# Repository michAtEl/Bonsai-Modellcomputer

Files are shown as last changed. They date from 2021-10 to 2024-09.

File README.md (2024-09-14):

# Bonsai-Modellcomputer
Der Bonsai-Modellcomputer wurde von Klaus Merkert für den Einsatz im Informatikunterricht entwickelt. Auf folgender Seite findet man unter anderem Schaltpläne und Platinenlayouts von Klaus Merkert zum Bau eines Bonsai-Modellcomputers:
http://www.hsg-kl.de/faecher/inf/material/bonsai/

Es gibt auch eine Simulation des Lerncomputers (https://bonsai.pinyto.de/), die im digitalen Informatik-Schulbuch http://inf-schule.de verwendet wird.

Viele Bauteile, die in den Plänen von Klaus Merkert verwendet werden, wurden abgekündigt und sind heue (Stand 2021) nicht mehr verfügbar.
Ziel dieses Projektes ist es deshalb, eine Version des Bonsai-Modellcomputer zu entwickeln, die möglichst leicht nachgebaut werden kann.

# Projekstatus
Der Prototyp funktioniert und wurde im Unterricht eingesetzt. In den Github-Issues sind einige kleinere Probleme beschrieben, die vor einem weiteren Nachbau behoben werden könnten.

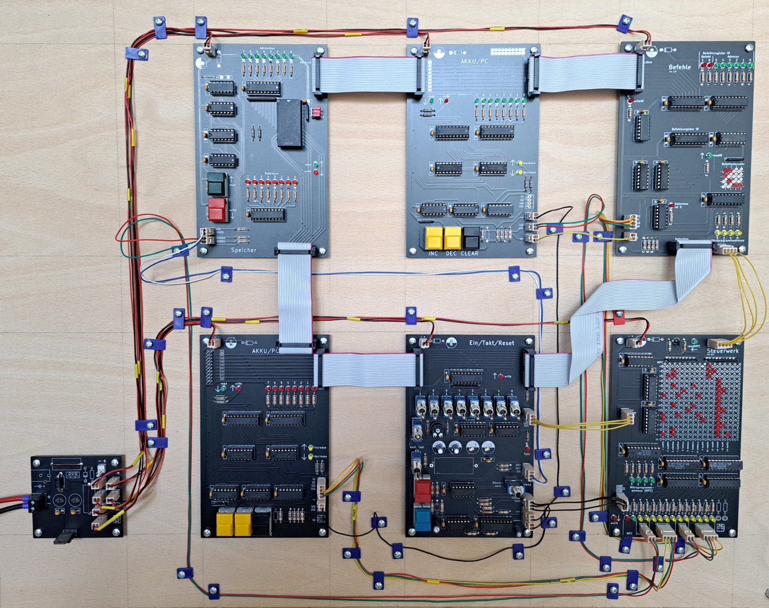
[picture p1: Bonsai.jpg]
Bonsai-Modellcomputer


# Änderungen gegenüber den Plänen von Klaus Merkert
- Die Namen und Reihenfolge der Steuersignale wurden an den Simulator angepasst (vgl. https://bonsai.pinyto.de/documentation/micro/)
- Alle Schaltpläne und Platinen wurden mit der Software KiCad gezeichnet (http://kicad.org).
- Für die Platinen wurden neue Layouts entwickelt, damit die Möglichkeiten eines doppelseitigen Layouts besser genutzt werden können.
- Die Steckverbinder zur Verbindung der Steuersignale sowie der Spannungsversorgung mit den Platinen wurden ersetzt durch Reichelt PSK (Alternativ kann man Molex KK verwenden. Diese Steckverbinder sind besser, aber auch deutlich teurer).
- Alle Bauteile der Familie 74LS wurden durch Bauteile der Familien 74HC oder 74HCT ersetzt.
- Zur Nullentdeckung auf der Platine Befehle wurde eine Wired-And-Verknüpfung mit Open-Collector-Ausgängen verwendet. Diese Wired-And-Verknüpfung wurde durch Gatter in einem 74HC08 ersetzt.
- Zur Erzeugung eines automatischen Taktsignals wird ein Mikrocontroller (Atmega 48-20P) verwendet. Der Quellcode liegt im Verzeichnis EinTaktReset-src. Der Quellcode kann mit dem Microchip Studio compiliert werden. Der Mikrocontroller kann anschließend über den ISP-Header auf der Platine EinTaktReset programmiert werden.

# Eine Bonsai nachbauen
## Beschaffung der Bauteile
- Flachbandkabel: Diese Flachbandkabel kann man aus IDE-Kabeln herstellen.
- Taster Digitast: Diese Schalter sind in den letzten Jahren sehr teuer geworden (ca. 5€ pro Taster). Kompatible Nachbauten findet man auf der Seite https://de.aliexpress.com/ unter der Bezeichnung PB86. Zur Sicherheit: Datenblatt (insbesondere Abmessungen und interne Schaltung) prüfen!
- Die Steckverbinder 

## Platinen fertigen lassen
Die Pläne wurden mit KiCad gezeichnet. In den *.kicad_sch-Dateien befinden sich die Schaltpläne, die Platinenlayouts sind in den *.kicad_pcb-Dateien. Um die Platinen fertigen zu lassen, muss man das Platinenlayout in ein Format exportieren, dass der Hersteller versteht. In der Regel ist das Gerber. Die Gerber-Exporte, die bei dem Prototypen verwendet wurden, liegen im Verzeichnis gerber. Diese Gerber-Dateien wurden von https://jlcpcb.com/ problemlos gefertigt.

## Platinen bestücken
Es werden nur bedrahtete Bauteile (keine SMD-Bauteile) verwendet, da bedrahtete Bauteile von Lötanfängern (z.B. Schülern) leichter bestückt werden können. Es ist sinnvoll, bei allen ICs je einen Sockel zu verwenden.

Der Bestückungsdruck der Platinen wird für Hinweise zur Bedienung des Rechners verwendet.
Die Bezeichnungen der Bauteile stehen nicht im Bestückungsdruck.
Man erfährt diese Bezeichnungen, indem man das KiCad-Projekt zu der Platinen, an der man gerade arbeitet, betrachtet. Dazu öffnet man zunächst die Projektdatei (.kicad_pro). Aus der Kicad-Projektansicht kann man dann den Schaltplan und das Board mit einem Doppelclick öffnen. Wenn man die Dateien so öffnet, sind Schaltplan und Board verknüpft. D.h.: Klickt man im Schaltplan / Board auf ein Bauteil, so wird dieses Bauteil automatisch auch im Bard / Schaltplan hervorgehoben. So versteht man leichter, welche Aufgabe ein bestimmtes Bauteil auf dem Board hat. 

Es empfiehlt sich, die Platinen in der folgenden Reihenfolge zu bestücken:
- Spanngsversorgung (KiCad-Projekt power-schmal). Diese Platine wird später benötigt, um andere Platinen zu testen.
- Akku und PC. Diese Platinen können einzeln getestet werden. Achtung: Die Platinen sind gleich, sie unterscheiden sich jedoch in der Farbe der LEDs und den Widerständen R2 und R2 (vgl. Schaltplan sowie [Bonsai.jpg](Bonsai.jpg))
- Speicher
- Ein/Takt/Reset. Nun können alle bisher gebauten Platinen gemeinsam getestet werden. Man verkabelt die Platinen. Dann kann man mit den Kippschaltern Zahlen eingeben, diese Zahlen speichern und anschließend wider auf den Datenbus schreiben.
- restliche Platinen

## Platine Ein/Takt/Reset
Von dieser Platine gibt es eine neue Version. Im Bild [Bonsai.jpg](Bonsai.jpg) ist noch die alte Version abgebildet. In der neuen Version wird der Takt von einem Mikrocontroller (ATmega48) erzeugt. Dieser Controller muss programmiert werden. Die Programmierung kann direkt in der Schaltung mit Hilfe der 6-poligen Pinleiste erfolgen. Man benötigt dazu einen ISP-Adapter für ATmega-Controller. Der Quellcode befindet sich im Ordner EinTaktReset-src.

## Platinen verdrahten
Bei der Verdrahtung kann man sich orientieren
- [am Bild des Computers](Bonsai.jpg)
- [Verdrahtung](Verdrahtung.svg) Tipp: Datei in Inkscape öffnen; die Datei ist im Maßstab 1:1 gezeichnet
- an der Verdrahtungsanleitung von Klaus Merkert (https://www.hsg-kl.de/faecher/inf/material/bonsai/bau/verdraht/index.php)

Crimpanleitung für die Steckverbinder Reichelt PSK: https://www.reichelt.de/reicheltpedia/index.php/Crimp_Anleitungen#Crimpen_von_PSK-Kontakten

Als Flachbandkabel kann man alte IDE-Kabel verwenden. Mann muss jedoch einige Leitungen abtrennen und neue Stecker crimpen.

Die Kabelhalter können mit einem 3D-Drucker gedruckt werden. Eine OpenSCAD-Datei befindet sich im Ordner Kabelhalter: [Kabelhalter.scad](Kabelhalter/Kabelhalter.scad)

## Spannungsversorgung
Der Bonsai läuft mit einer Gleichspannung von 5V. Es mehrere Möglichkeiten, wie man diese Spannung bereitstellen kann:

- Man verwendet ein Festspannungsnetzteil, das 5V ausgibt. Aus Lochrasterplatinenmaterial baut man eine Platine, auf der sich eine Buchse für das Netzteil sowie sechs 2-polige Steckerleisten für 2-polige PSK-Stecker befinden (pro Platine eine Steckerleiste).
- Man baut eine kleine Platine mit einem Festspannungsregler (7805). Dazu kann man z.B. die Platine im Ordner power-schmal verwenden. Diese Platine benötigt eine Eingangsspannung, die irgendwo zwischen ca. 7V und ca. 15V liegen sollte. Dazu kann man z.B. ein Labornetzgerät verwenden.  Das Labornetzgerät hat gegenüber einem Steckernetzteil den Vorteil, dass man die Stromstärke an dem Netzteil ablesen kann und so eine kontrolle hat, ob der Bonsai richtig funktioniert. Bei dem vollständigen Bonsai liegt die Stromstärke (je nach dem, wie viele LEDs gerade leuchten und welche Vorwiderstände für die LEDs verwendet wurden) bei ca. 50mA - 300mA.

## Helligkeit der LEDs
Die Leds sind sehr hell. Bei einem Nachbau könnte man größere Vorwiderstände verwenden. Nach der Anschaffung der LEDs könnte man die Helligkeit einer LED bei verschiedenen Vorwiderständen ausprobieren (Led in Reihe schalten mit Vorwiderstand) und dann festlegen, welchen Vorwiderstand man verwendet.

Bei LEDs, die von einem Pin eines 74HCXX getrieben werden, sollte der Vorwiderstand mindestens 600Ohm betragen, wenn man innerhalb der Empfehlungen von TI bleiben möchte (vgl. Issue #5). Dies gilt jedoch nicht für LEDs, die von einem 74HC540 oder 74HC541 getrieben werden, da diese beiden ICs Leistungstreiber sind.

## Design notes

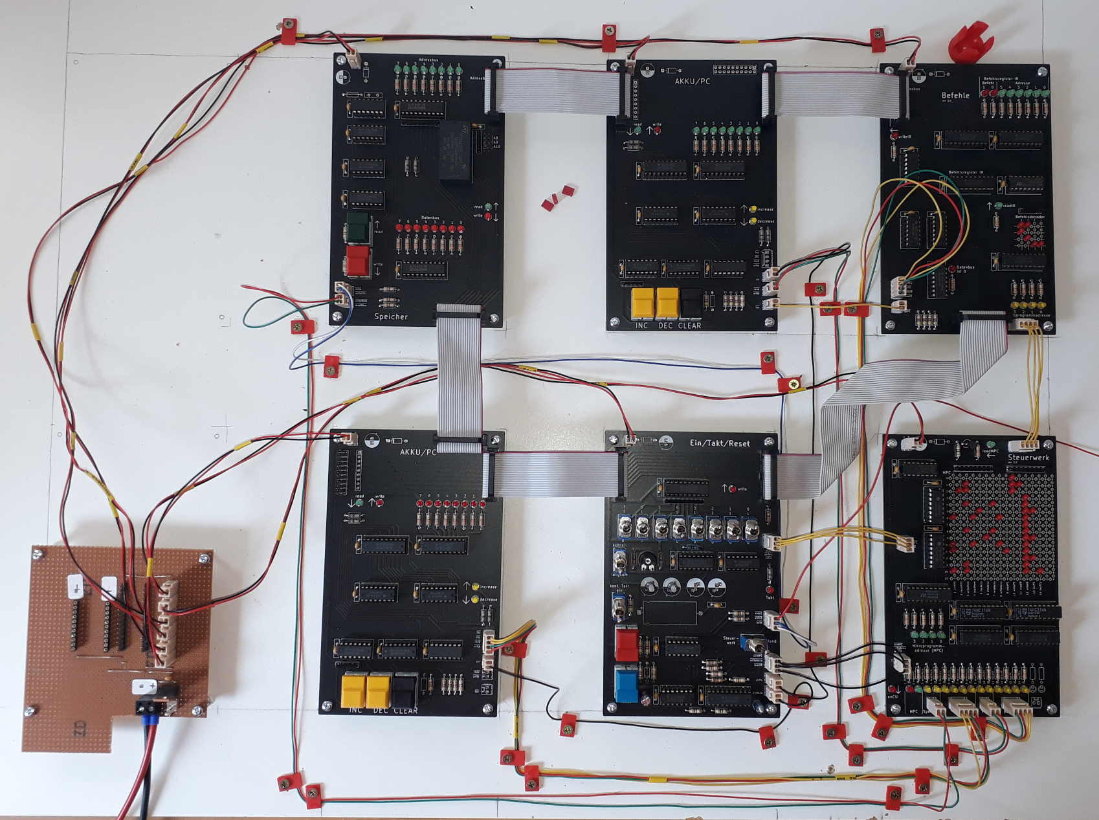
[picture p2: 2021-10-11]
Prototyp.jpg

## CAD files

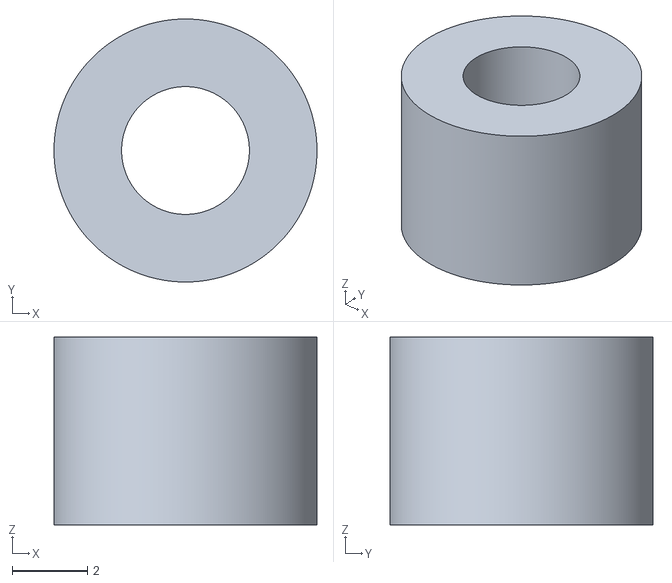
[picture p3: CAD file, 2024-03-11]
Distanzhülse/Distanzhülse.stl
7.00 x 7.00 x 5.00

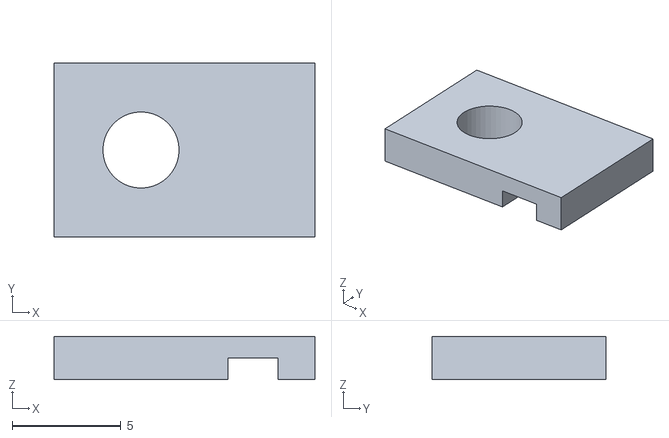
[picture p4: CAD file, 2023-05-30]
Kabelhalter/Kabelhalter 2 Kabel.stl
12.0 x 8.00 x 2.00

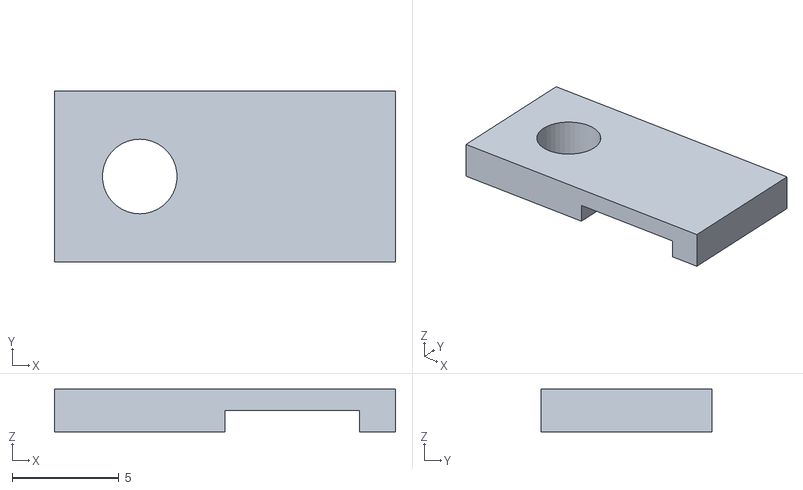
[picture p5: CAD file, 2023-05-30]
Kabelhalter/Kabelhalter 6 Kabel.stl
16.0 x 8.00 x 2.00

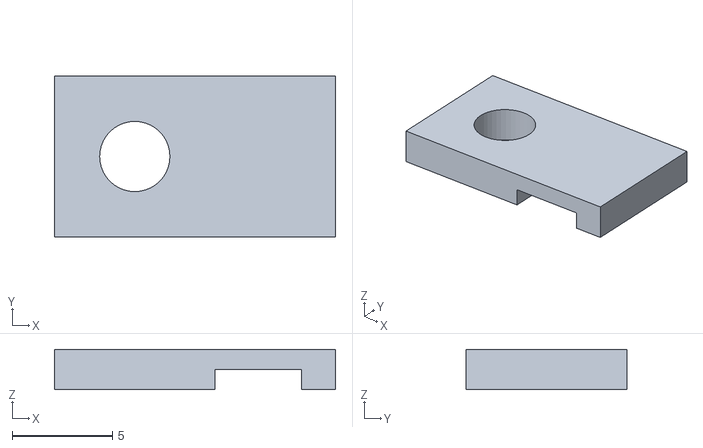
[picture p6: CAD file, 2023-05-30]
Kabelhalter/Kabelhalter 4 Kabel.stl
14.0 x 8.00 x 2.00

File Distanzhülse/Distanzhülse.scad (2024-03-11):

difference() {
    cylinder(5, 3.5, 3.5, $fn=300);
    cylinder(5, 1.7, 1.7, $fn=300);
}

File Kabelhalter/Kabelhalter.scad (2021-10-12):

anzahlKabel = 2;

// Breite pro Kabel
bKabel = 1;

// Höhe pro Kabel
hKabel = 1;

difference() {
    cube(size=[10 + anzahlKabel*bKabel, 8, 1+hKabel]);
    
    // Bohrloch
    translate([4, 4, -1])
        cylinder(10, 3.5/2, 3.5/2, $fn=40);
    
    // Aussparung für Kabel
    translate([8, -5, -1]){
        cube(size=[anzahlKabel*bKabel+0.3, 20, 1+hKabel]);
    }
}

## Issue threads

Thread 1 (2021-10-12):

manueller Takt funktioniert nicht immer

michAtEl, 2021-10-12:
Platine Ein/Takt/Reset

Der manuelle Takt funktioniert nicht, wenn der automatische Takt beim Abschalten auf 1stehen geblieben ist.
Workaround ohne Änderung der Platine: Man kann den automatischen für einen kurzen Zeitraum wieder einschalten, bis er auf 0 steht.
Behebung des Problems: Einen Multiplexer verwenden, um (abhängig von der Schalterstellen automatischer Takt ein/aus) den automatischen oder den manuellen Takt auszugeben

Closed 2024-03-11.

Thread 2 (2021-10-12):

Steuerwerk, Befehle: Vias zu klein

michAtEl, 2021-10-12:
Auf den Platinen Steuerwerk und Befehle sind die Vias so klein, dass sie außerhalb der Empfehlungen einiger Platinenhersteller liegen. Vor einem Nachbau sollten die Vias vergrößert werden.

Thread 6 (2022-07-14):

Probleme mit dem Bonsai-Modellrechner

finnknauber, 2022-07-14:
In Rahmen eines Schulprojekts in der Klassenstufe 11 haben einige Mitschüler und ich den von Ihnen konzipierten "Bonsai-Modellrechner" gebaut. Nachdem die Inbetriebnahme nicht ganz erfolgreich verlief, ist uns folgendes aufgefallen:

- Steuerwerk: Geht ein Ausgang eines der beiden 74LS138 auf Low, wird über einen Vorwiderstand eine LED in der Matrix aktiviert, deren Anode mit einem Eingang eines 74LS374 verbunden ist. Da an der LED dann ca. 2V abfallen (unabhängig von der Dimensionierung des Vorwiderstands), erkennt der 74LS374 kein eindeutiges Low, was zur Fehlfunktion der nachfolgenden Schaltung führt.

- Ebenso: Platine "Befehle" (Befehlsdecoder): 74HC139/74HC540, Ersatz der LEDs durch Dioden (1N4148) behebt das Problem dort.

- Speichermodul: Falsche Beschriftung eines 4-fach-AND-Gatters mit 74HC14 (6-fach Inverter) statt 74HC08,

- Dimensionierung der Widerstandsnetze fehlt.

michAtEl, 2022-09-15:
zu Punkt 1: Ich habe in meinem Aufbau gar keine ICs der Familie 74LS mehr. Leider sind in den Schaltplänen diese ICs noch eingetragen, obwohl nur ICs der Familien 74HC oder 74HCT verwendet werden sollten. Die ICs U5 und U6 auf dem Steuerwerk sollten 74HC374 sein, da ICs der Familie 74HC ein Potential von 2V als Low erkennen (wobei dies in der Regel nur für Potentiale kleiner 1,5V garantiert wird; vgl. Horowitz Hill: The Art of Electronics, 3. Auflage, Abb. 12.6 auf S. 797) .

zu Punkt 2: Wurde hier wirklich ein 74HC540 verwendet? Der funktioniert bei mir. Wenn man LEDs verwendet, ist es auch wichtig, dass der Mikroprogrammzähler (74HC161) wirklich aus der Familie 74HC ist, da dieser IC ebenfalls die Signale, die über die LEDs auf 2V gezogen werden, als Low erkennen muss. Dies LEDs kann man aber problemlos durch nicht leuchtende Dioden ersetzen - der aktuelle Wert des Busses wird ja auch von den Dioden 26 bis 29 (Platine Befehle) angezeigt.

zu Punkt 4: Ich verwende im Steuerwerk Widerstandsnetze mit 10kOhm pro Widerstand. Bei einem kleineren Widerstand ist die Stromstärke durch die LED deutlich größer und die LED heller. Dies führt aber dazu, dass die Spannung über der LED (= Potential an den Eingängen der ICs) etwas größer wird. Da die ICs74HC374 ohnehin schon außerhalb der 1,5V, die garantiert als Low erkannt werden, betrieben wird, habe ich den Widerstand so groß gewählt, dass man das Leuchten der LEDs gerade noch erkennt.

Bei Gelegenheit werde ich die Beschriftungen der ICs korrigieren.

michAtEl, 2024-03-11:
Beschriftungen der Bauteile wurden ergänzt.

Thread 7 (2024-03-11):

Footprint Transistor Steuerwerk

michAtEl, 2024-03-11:
Auf der Platine Steuerwerk befindet sich ein Transistor, in dessen Footprint Beinchen vertauscht sind. Beim Einbau des Transistors müssen die Beinchen gebogen werden, so dass sie an der richtigen Stelle festgelötet werden.

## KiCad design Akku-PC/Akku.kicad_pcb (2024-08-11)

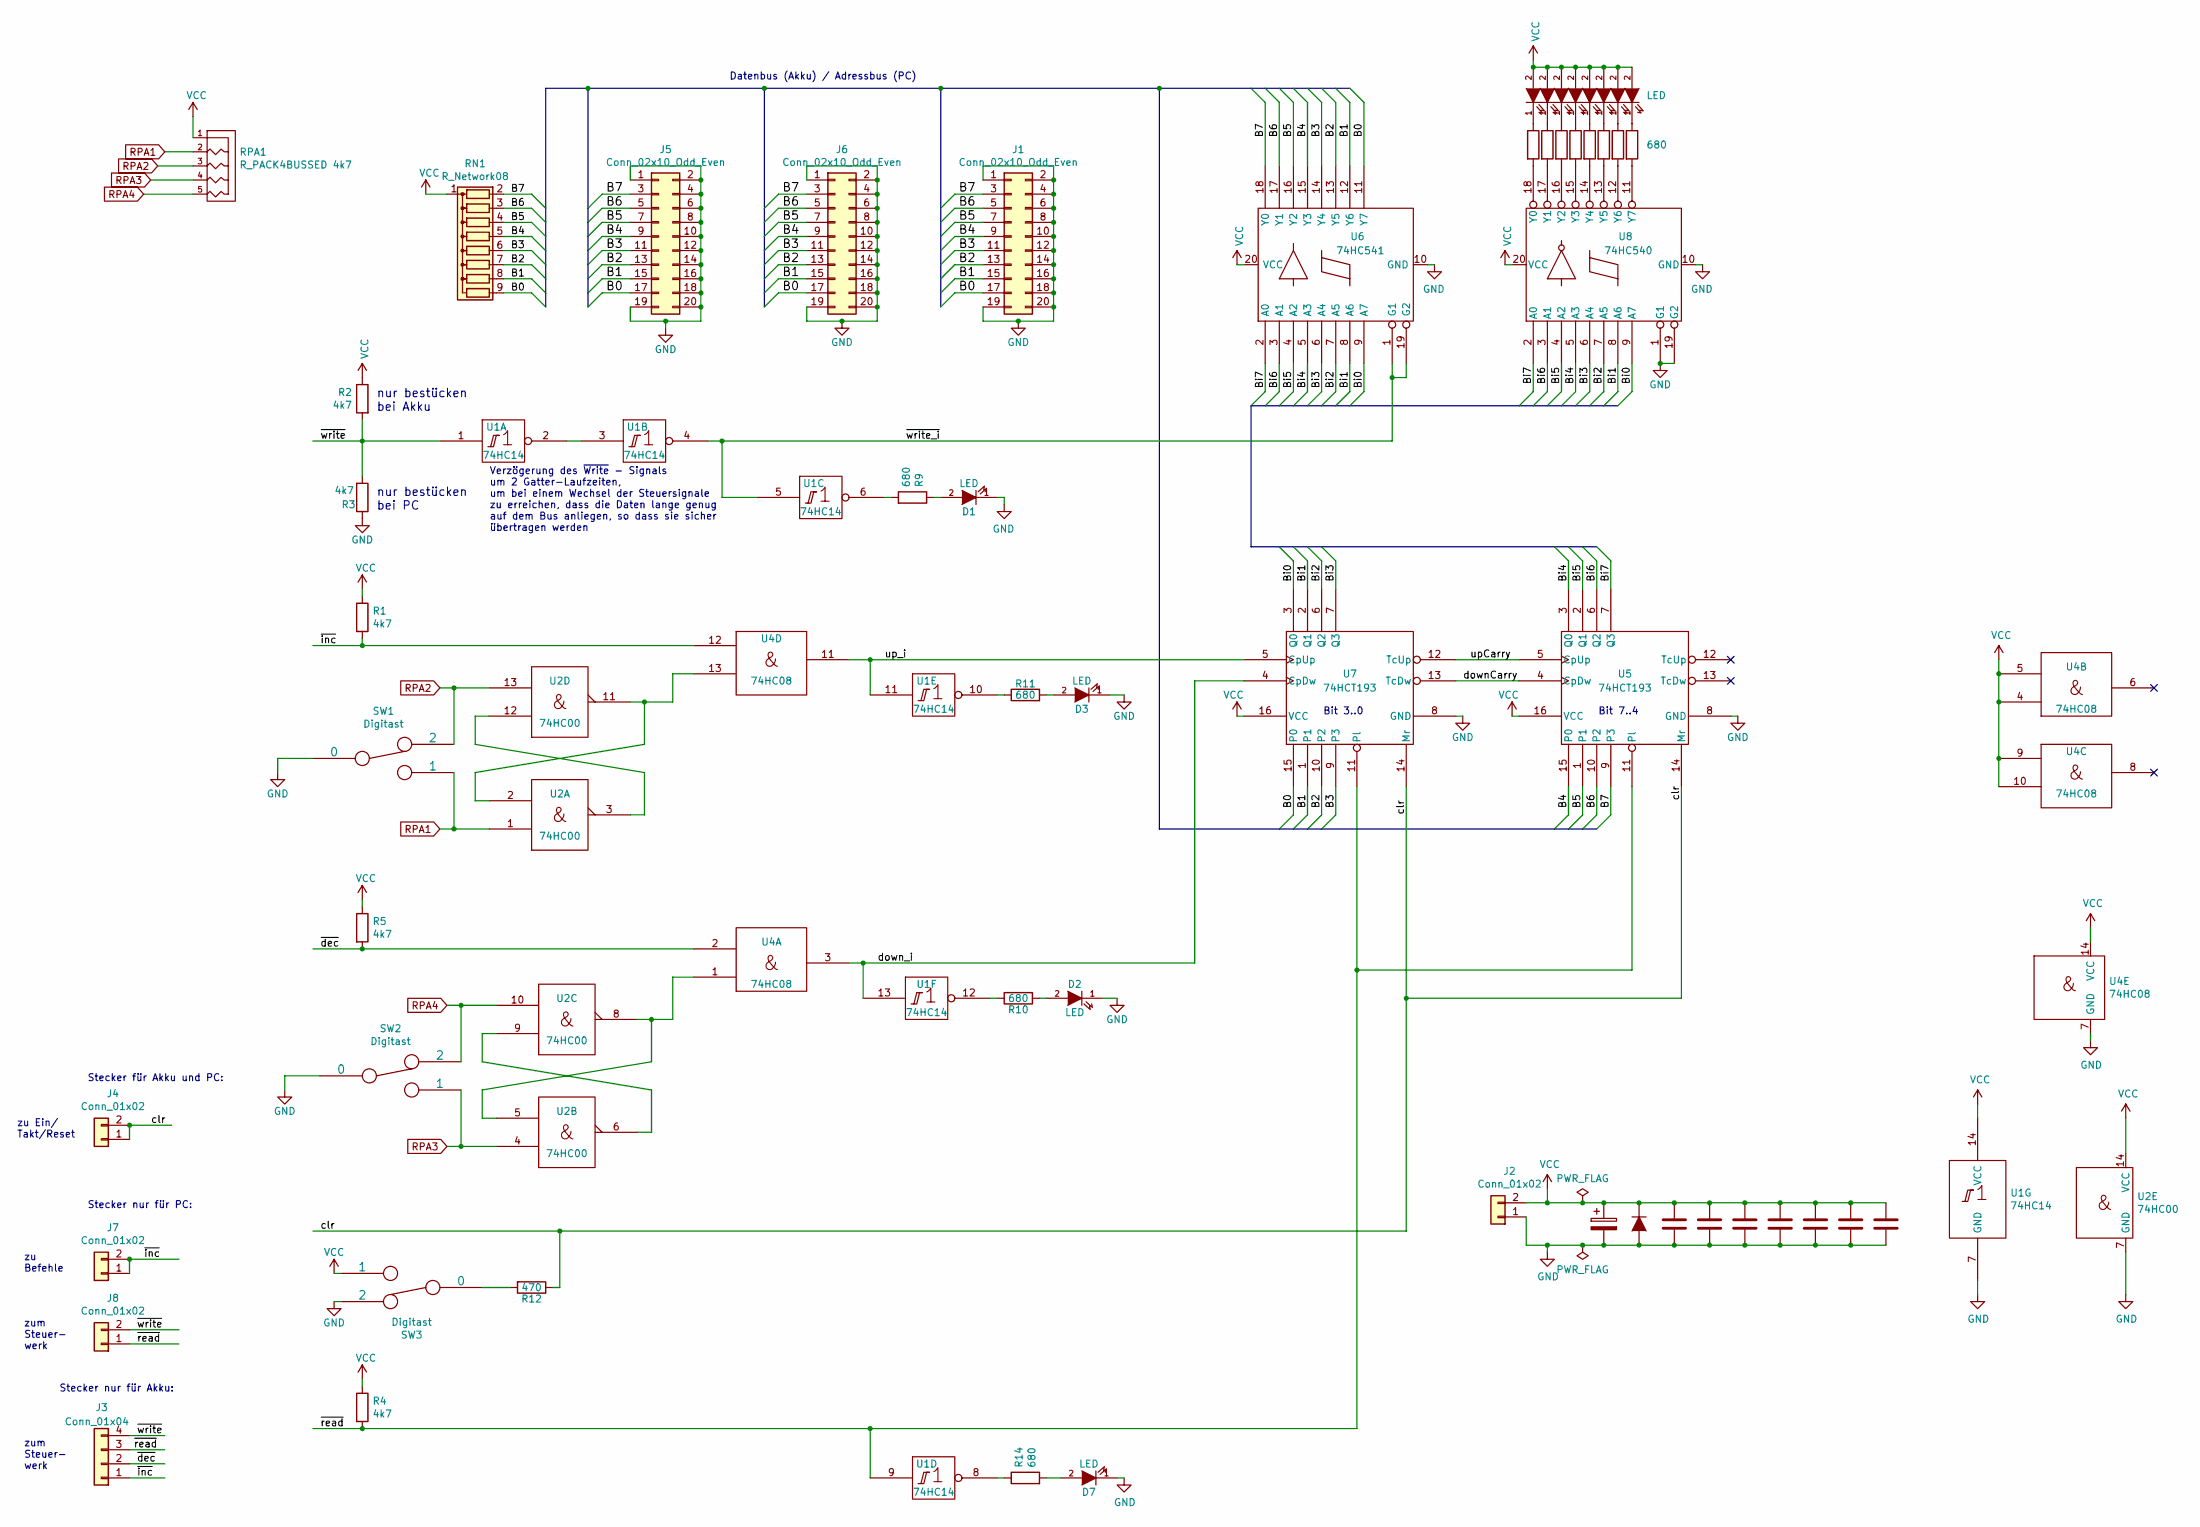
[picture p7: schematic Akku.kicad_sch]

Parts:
C1, C2, C3, C5, C6, C7, C8: 100n; C_Disc_D10.0mm_W2.5mm_P5.00mm
C4: CP; CP_Radial_D8.0mm_P2.50mm
D1, D2, D3, D4, D5, D6, D7, D8, D9, D10, D11, D12: LED; LED_D3.0mm
D13: D; D_A-405_P10.16mm_Horizontal
J1, J5, J6: Conn_02x10_Odd_Even; PinHeader_2x10_P2.54mm_Vertical
J2, J4, J7, J8: Conn_01x02; Molex_KK-254_AE-6410-02A_1x02_P2.54mm_Vertical
J3: Conn_01x04; Molex_KK-254_AE-6410-04A_1x04_P2.54mm_Vertical
R1, R2, R3, R4, R5: 4k7; R_Axial_DIN0207_L6.3mm_D2.5mm_P10.16mm_Horizontal
R9, R10, R11, R13, R14, R15, R16, R17, R18, R19, R20, R21: 680; R_Axial_DIN0207_L6.3mm_D2.5mm_P10.16mm_Horizontal
R12: 470; R_Axial_DIN0207_L6.3mm_D2.5mm_P10.16mm_Horizontal
RN1: R_Network08; R_Array_SIP9
RPA1: R_PACK4BUSSED 4k7; R_Array_SIP5
SW1, SW2, SW3: Digitast; Switch_Digitast
U1: 74HC14; DIP-14_W7.62mm_Socket_LongPads
U2: 74HC00; DIP-14_W7.62mm_Socket_LongPads
U4: 74HC08; DIP-14_W7.62mm_Socket_LongPads
U5, U7: 74HCT193; DIP-16_W7.62mm_Socket_LongPads
U6: 74HC541; DIP-20_W7.62mm_Socket_LongPads
U8: 74HC540; DIP-20_W7.62mm_Socket_LongPads

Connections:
/B0: J1.17, J5.17, J6.17, RN1.9 (R8), U6.11 (Y7), U7.15 (P0)
/B1: J1.15, J5.15, J6.15, RN1.8 (R7), U6.12 (Y6), U7.1
/B2: J1.13, J5.13, J6.13, RN1.7 (R6), U6.13 (Y5), U7.10 (P2)
/B3: J1.11, J5.11, J6.11, RN1.6 (R5), U6.14 (Y4), U7.9 (P3)
/B4: J1.9, J5.9, J6.9, RN1.5 (R4), U5.15 (P0), U6.15 (Y3)
/B5: J1.7, J5.7, J6.7, RN1.4 (R3), U5.1, U6.16 (Y2)
/B6: J1.5, J5.5, J6.5, RN1.3 (R2), U5.10 (P2), U6.17 (Y1)
/B7: J1.3, J5.3, J6.3, RN1.2 (R1), U5.9 (P3), U6.18 (Y0)
/Bi0: U6.9 (A7), U7.3 (Q0), U8.9 (A7)
/Bi1: U6.8 (A6), U7.2 (Q1), U8.8 (A6)
/Bi2: U6.7 (A5), U7.6 (Q2), U8.7 (A5)
/Bi3: U6.6 (A4), U7.7 (Q3), U8.6 (A4)
/Bi4: U5.3 (Q0), U6.5 (A3), U8.5 (A3)
/Bi5: U5.2 (Q1), U6.4 (A2), U8.4 (A2)
/Bi6: U5.6 (Q2), U6.3 (A1), U8.3 (A1)
/Bi7: U5.7 (Q3), U6.2 (A0), U8.2 (A0)
/clr: J4.1, J4.2, R12.1, U5.14 (Mr), U7.14 (Mr)
/downCarry: U5.4 (CpDw), U7.13 (TcDw)
/down_i: U1.13, U4.3, U7.4 (CpDw)
/upCarry: U5.5 (CpUp), U7.12 (TcUp)
/up_i: U1.11, U4.11, U7.5 (CpUp)
/~dec: J3.2, R5.2, U4.2
/~inc: J3.1, J7.1, J7.2, R1.2, U4.12
/~read: J3.3, J8.1, R4.2, U1.9, U5.11 (Pl), U7.11 (Pl)
/~write_i: U1.4, U1.5, U6.1 (G1), U6.19 (G2)
/~write: J3.4, J8.2, R2.2, R3.2, U1.1
GND: C1.1, C2.1, C3.1, C4.2, C5.1, C6.1, C7.1, C8.1, D1.1 (K), D2.1 (K), D3.1 (K), D7.1 (K), D13.2 (A), J1.1, J1.2, J1.4, J1.6, J1.8, J1.10, J1.12, J1.14, J1.16, J1.18, J1.19, J1.20, J2.1, J5.1, J5.2, J5.4, J5.6, J5.8, J5.10, J5.12, J5.14, J5.16, J5.18, J5.19, J5.20, J6.1, J6.2, J6.4, J6.6, J6.8, J6.10, J6.12, J6.14, J6.16, J6.18, J6.19, J6.20, R3.1, SW1.0, SW2.0, SW3.2, U1.7 (GND), U2.7 (GND), U4.7 (GND), U5.8 (GND), U6.10 (GND), U7.8 (GND), U8.1 (G1), U8.10 (GND), U8.19 (G2)
unnamed: D1.2 (A), R9.1
unnamed: D2.2 (A), R10.2
unnamed: D3.2 (A), R11.2
unnamed: D4.1 (K), R13.1
unnamed: D5.1 (K), R15.1
unnamed: D6.1 (K), R16.1
unnamed: D7.2 (A), R14.2
unnamed: D8.1 (K), R17.1
unnamed: D9.1 (K), R18.1
unnamed: D10.1 (K), R19.1
unnamed: D11.1 (K), R20.1
unnamed: D12.1 (K), R21.1
unnamed: R9.2, U1.6
unnamed: R10.1, U1.12
unnamed: R11.1, U1.10
unnamed: R12.2, SW3.0
unnamed: R14.1, U1.8
unnamed: U1.2, U1.3
unnamed: U2.5, U2.8, U4.1
unnamed: U2.6, U2.9
unnamed: U2.2, U2.11, U4.13
unnamed: U2.3, U2.12
unnamed: R13.2, U8.18 (Y0)
unnamed: R15.2, U8.17 (Y1)
unnamed: R16.2, U8.16 (Y2)
unnamed: R17.2, U8.15 (Y3)
unnamed: R18.2, U8.14 (Y4)
unnamed: R19.2, U8.13 (Y5)
unnamed: R20.2, U8.12 (Y6)
unnamed: R21.2, U8.11 (Y7)
RPA1: RPA1.2, SW1.1, U2.1
RPA2: RPA1.3, SW1.2, U2.13
RPA3: RPA1.4, SW2.1, U2.4
RPA4: RPA1.5, SW2.2, U2.10
VCC: C1.2, C2.2, C3.2, C4.1, C5.2, C6.2, C7.2, C8.2, D4.2 (A), D5.2 (A), D6.2 (A), D8.2 (A), D9.2 (A), D10.2 (A), D11.2 (A), D12.2 (A), D13.1 (K), J2.2, R1.1, R2.1, R4.1, R5.1, RN1.1 (common), RPA1.1, SW3.1, U1.14 (VCC), U2.14 (VCC), U4.4, U4.5, U4.9, U4.10, U4.14 (VCC), U5.16 (VCC), U6.20 (VCC), U7.16 (VCC), U8.20 (VCC)

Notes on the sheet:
zum Steuer- werk
Stecker für Akku und PC:
Bit 7..4
nur bestücken bei Akku
zu Ein/ Takt/Reset
Stecker nur für PC:
nur bestücken bei PC
Datenbus (Akku) / Adressbus (PC)
Bit 3..0
Verzögerung des ~{Write} - Signals um 2 Gatter-Laufzeiten, um bei einem Wechsel der Steuersignale zu erreichen, dass die Daten lange genug auf dem Bus anliegen, so dass sie sicher übertragen werden
zu Befehle
Stecker nur für Akku:

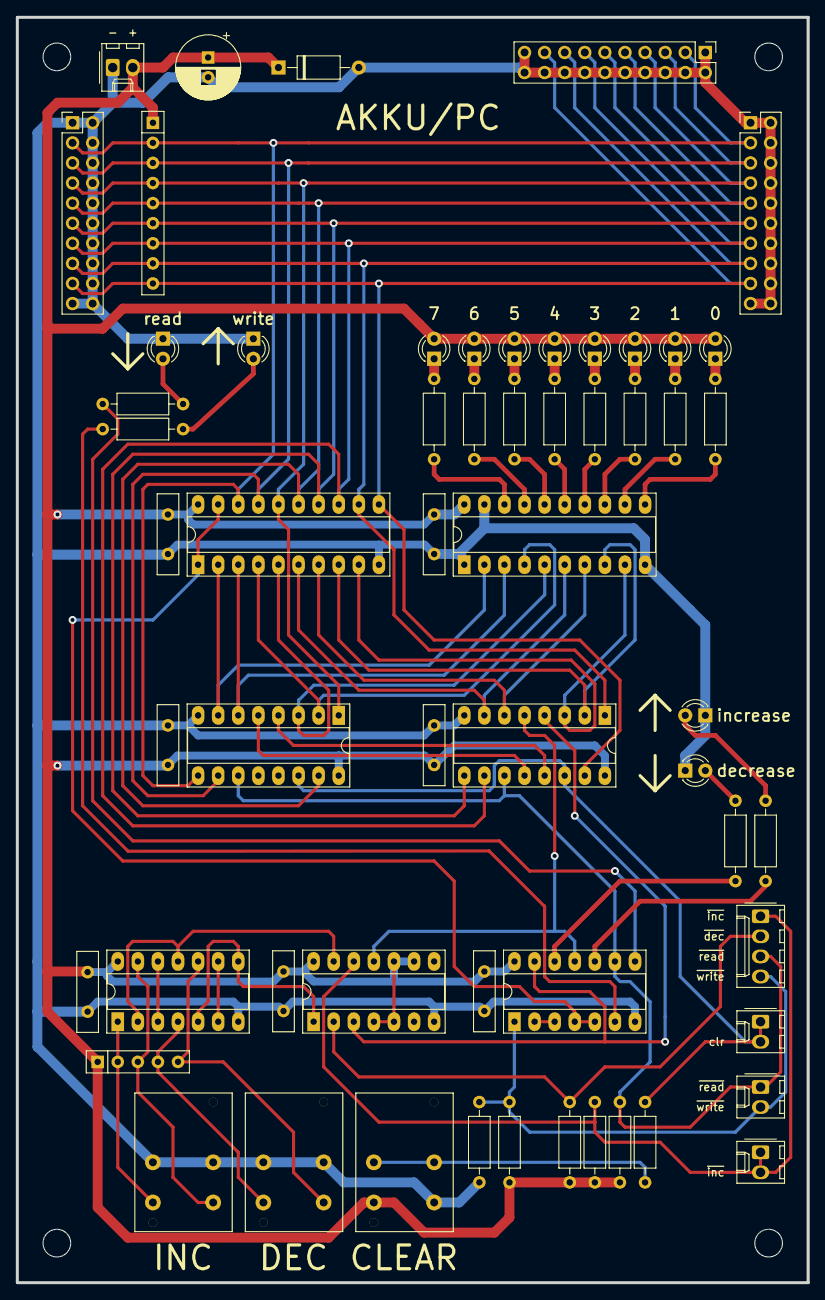
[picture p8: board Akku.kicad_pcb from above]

Board: 2 copper layers, 100.0 x 160.0 mm, 59 parts (0 on the bottom side), 62 nets.

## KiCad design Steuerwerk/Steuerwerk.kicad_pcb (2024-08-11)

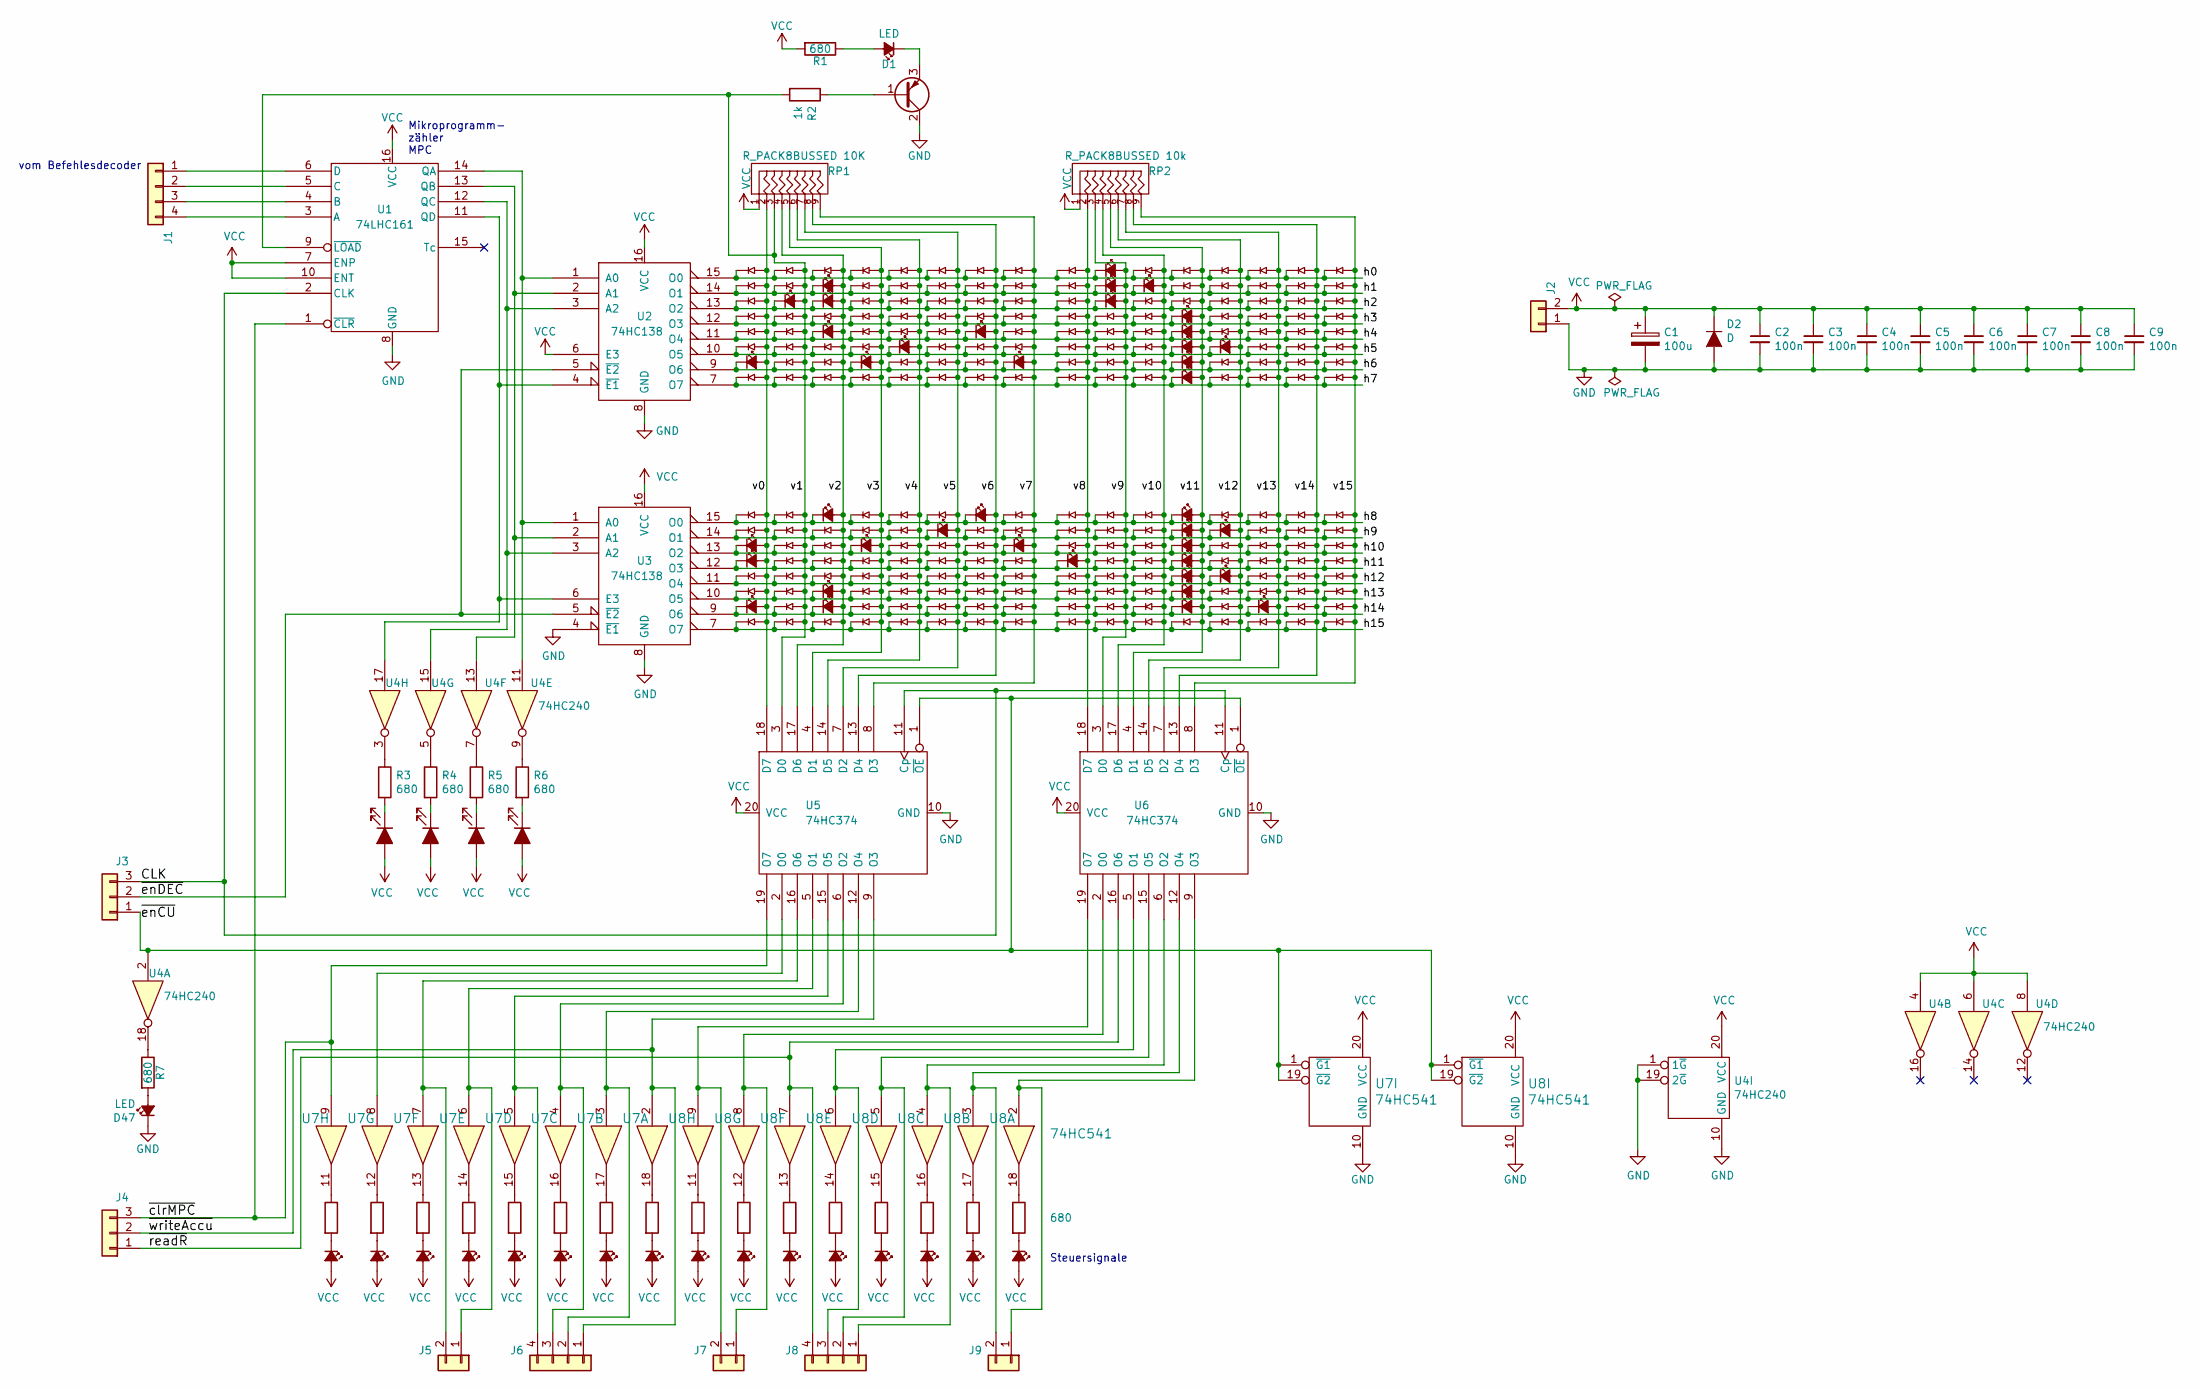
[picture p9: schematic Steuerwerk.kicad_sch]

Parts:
C1: 100u; CP_Radial_D8.0mm_P2.50mm
C2, C3, C4, C5, C6, C7, C8, C9: 100n; C_Disc_D10.0mm_W2.5mm_P5.00mm
D1, D43, D44, D45, D46, D47, D48, D49, D50, D51, D52, D53, D54, D55, D56, D57, D58, D59, D60, D61, D62, D63: LED; LED_D3.0mm
D2: D; D_A-405_P10.16mm_Horizontal
D3, D4, D5, D6, D7, D8, D9, D10, D11, D12, D13, D14, D15, D16, D17, D18, D19, D20, D21, D22, D23, D24, D25, D26, D27, D28, D29, D30, D31, D32, D33, D34, D35, D36, D37, D38, D39, D40, D41, D42: Led_Small; LED_Diodenmatrix
D64, D65, D66, D67, D68, D69, D70, D71, D72, D73, D74, D75, D76, D77, D78, D79, D80, D81, D82, D83, D84, D85, D86, D87, D88, D89, D90, D91, D92, D93, D94, D95, D96, D97, D98, D99, D100, D101, D102, D103, D104, D105, D106, D107, D108, D109, D110, D111, D112, D113, D114, D115, D116, D117, D118, D119, D120, D121, D122, D123, D124, D125, D126, D127, D128, D129, D130, D131, D132, D133, D134, D135, D136, D137, D138, D139, D140, D141, D142, D143, D144, D145, D146, D147, D148, D149, D150, D151, D152, D153, D154, D155, D156, D157, D158, D159, D160, D161, D162, D163, D164, D165, D166, D167, D168, D169, D170, D171, D172, D173, D174, D175, D176, D177, D178, D179, D180, D181, D182, D183, D184, D185, D186, D187, D188, D189, D190, D191, D192, D193, D194, D195, D196, D197, D198, D199, D200, D201, D202, D203, D204, D205, D206, D207, D208, D209, D210, D211, D212, D213, D214, D215, D216, D217, D218, D219, D220, D221, D222, D223, D224, D225, D226, D227, D228, D229, D230, D231, D232, D233, D234, D235, D236, D237, D238, D239, D240, D241, D242, D243, D244, D245, D246, D247, D248, D249, D250, D251, D252, D253, D254, D255, D256, D257, D258, D259, D260, D261, D262, D263, D264, D265, D266, D267, D268, D269, D270, D271, D272, D273, D274, D275, D276, D277, D278, D279: bonsai_Led_Small_Platzhalter; LED_Diodenmatrix_Platzhalter
J1, J6, J8: Conn_01x04; Molex_KK-254_AE-6410-04A_1x04_P2.54mm_Vertical
J2, J5, J7, J9: Conn_01x02; Molex_KK-254_AE-6410-02A_1x02_P2.54mm_Vertical
J3, J4: Conn_01x03; Molex_KK-254_AE-6410-03A_1x03_P2.54mm_Vertical
Q1: Q_PNP_BCE; TO-92_Inline_Wide
R1, R3, R4, R5, R6, R7, R8, R9, R10, R11, R12, R13, R14, R15, R16, R17, R18, R19, R20, R21, R22, R23: 680; R_Axial_DIN0207_L6.3mm_D2.5mm_P10.16mm_Horizontal
R2: 1k; R_Axial_DIN0207_L6.3mm_D2.5mm_P10.16mm_Horizontal
RP1: R_PACK8BUSSED 10K; SIP9_Housing_BigPads
RP2: R_PACK8BUSSED 10k; SIP9_Housing_BigPads
U1: 74LHC161; DIP-16_W7.62mm_Socket_LongPads
U2, U3: 74HC138; DIP-16_W7.62mm_Socket_LongPads
U4: 74HC240; DIP-20_W7.62mm_Socket_LongPads
U5, U6: 74HC374; DIP-20_W7.62mm_Socket_LongPads
U7, U8: 74HC541; DIP-20_W7.62mm_Socket_LongPads

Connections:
/CLK: J3.3, U1.2 (CLK), U5.11 (Cp), U6.11 (Cp)
/h0: D4.1 (K), D64.1 (K), D65.1 (K), D66.1 (K), D67.1 (K), D68.1 (K), D69.1 (K), D70.1 (K), D71.1 (K), D173.1 (K), D174.1 (K), D175.1 (K), D176.1 (K), D177.1 (K), D178.1 (K), D179.1 (K), U2.15 (O0)
/h1: D3.1 (K), D5.1 (K), D6.1 (K), D72.1 (K), D73.1 (K), D74.1 (K), D75.1 (K), D76.1 (K), D77.1 (K), D78.1 (K), D180.1 (K), D181.1 (K), D182.1 (K), D183.1 (K), D184.1 (K), D185.1 (K), U2.14 (O1)
/h2: D7.1 (K), D8.1 (K), D9.1 (K), D79.1 (K), D80.1 (K), D81.1 (K), D82.1 (K), D83.1 (K), D84.1 (K), D186.1 (K), D187.1 (K), D188.1 (K), D189.1 (K), D190.1 (K), D191.1 (K), D192.1 (K), U2.13 (O2)
/h3: D11.1 (K), D85.1 (K), D86.1 (K), D87.1 (K), D88.1 (K), D89.1 (K), D90.1 (K), D91.1 (K), D92.1 (K), D193.1 (K), D205.1 (K), D218.1 (K), D232.1 (K), D242.1 (K), D254.1 (K), D255.1 (K), U2.12 (O3)
/h4: D12.1 (K), D13.1 (K), D14.1 (K), D93.1 (K), D94.1 (K), D95.1 (K), D96.1 (K), D97.1 (K), D98.1 (K), D194.1 (K), D206.1 (K), D219.1 (K), D233.1 (K), D243.1 (K), D256.1 (K), D257.1 (K), U2.11 (O4)
/h5: D15.1 (K), D16.1 (K), D17.1 (K), D99.1 (K), D100.1 (K), D101.1 (K), D102.1 (K), D103.1 (K), D104.1 (K), D105.1 (K), D195.1 (K), D207.1 (K), D220.1 (K), D244.1 (K), D258.1 (K), D259.1 (K), U2.10 (O5)
/h6: D10.1 (K), D18.1 (K), D19.1 (K), D20.1 (K), D106.1 (K), D107.1 (K), D108.1 (K), D109.1 (K), D110.1 (K), D196.1 (K), D208.1 (K), D221.1 (K), D234.1 (K), D245.1 (K), D260.1 (K), D261.1 (K), U2.9 (O6)
/h7: D21.1 (K), D111.1 (K), D112.1 (K), D113.1 (K), D114.1 (K), D115.1 (K), D116.1 (K), D117.1 (K), D118.1 (K), D197.1 (K), D209.1 (K), D222.1 (K), D235.1 (K), D246.1 (K), D262.1 (K), D263.1 (K), U2.7 (O7)
/h8: D22.1 (K), D23.1 (K), D24.1 (K), D119.1 (K), D120.1 (K), D121.1 (K), D122.1 (K), D123.1 (K), D124.1 (K), D198.1 (K), D210.1 (K), D223.1 (K), D236.1 (K), D247.1 (K), D264.1 (K), D265.1 (K), U3.15 (O0)
/h9: D25.1 (K), D26.1 (K), D27.1 (K), D125.1 (K), D126.1 (K), D127.1 (K), D128.1 (K), D129.1 (K), D130.1 (K), D131.1 (K), D199.1 (K), D211.1 (K), D224.1 (K), D248.1 (K), D266.1 (K), D267.1 (K), U3.14 (O1)
/h10: D28.1 (K), D29.1 (K), D30.1 (K), D31.1 (K), D132.1 (K), D133.1 (K), D134.1 (K), D135.1 (K), D136.1 (K), D200.1 (K), D212.1 (K), D225.1 (K), D237.1 (K), D249.1 (K), D268.1 (K), D269.1 (K), U3.13 (O2)
/h11: D32.1 (K), D33.1 (K), D34.1 (K), D137.1 (K), D138.1 (K), D139.1 (K), D140.1 (K), D141.1 (K), D142.1 (K), D143.1 (K), D213.1 (K), D226.1 (K), D238.1 (K), D250.1 (K), D270.1 (K), D271.1 (K), U3.12 (O3)
/h12: D35.1 (K), D36.1 (K), D144.1 (K), D145.1 (K), D146.1 (K), D147.1 (K), D148.1 (K), D149.1 (K), D150.1 (K), D151.1 (K), D201.1 (K), D214.1 (K), D227.1 (K), D251.1 (K), D272.1 (K), D273.1 (K), U3.11 (O4)
/h13: D37.1 (K), D38.1 (K), D152.1 (K), D153.1 (K), D154.1 (K), D155.1 (K), D156.1 (K), D157.1 (K), D158.1 (K), D202.1 (K), D215.1 (K), D228.1 (K), D239.1 (K), D252.1 (K), D274.1 (K), D275.1 (K), U3.10 (O5)
/h14: D39.1 (K), D40.1 (K), D41.1 (K), D42.1 (K), D159.1 (K), D160.1 (K), D161.1 (K), D162.1 (K), D163.1 (K), D164.1 (K), D203.1 (K), D216.1 (K), D229.1 (K), D240.1 (K), D276.1 (K), D277.1 (K), U3.9 (O6)
/h15: D165.1 (K), D166.1 (K), D167.1 (K), D168.1 (K), D169.1 (K), D170.1 (K), D171.1 (K), D172.1 (K), D204.1 (K), D217.1 (K), D230.1 (K), D231.1 (K), D241.1 (K), D253.1 (K), D278.1 (K), D279.1 (K), U3.7 (O7)
/~clrMPC: J4.3, U1.1 (~CLR), U5.19 (O7), U7.9
/~enCU: J3.1, U4.2, U5.1 (~OE), U6.1 (~OE), U7.1 (~G1), U7.19 (~G2), U8.1 (~G1), U8.19 (~G2)
/~enDEC: J3.2, U2.5 (~E2), U3.5 (~E2)
/~readR: J4.1, J8.4, U6.16 (O6), U8.7
/~writeAccu: J4.2, J6.1, U5.9 (O3), U7.2
GND: C1.2, C2.2, C3.2, C4.2, C5.2, C6.2, C7.2, C8.2, C9.2, D2.2 (A), D47.1 (K), J2.1, Q1.2 (C), U1.8 (GND), U2.8 (GND), U3.4 (~E1), U3.8 (GND), U4.1 (1~G), U4.10 (GND), U4.19 (2~G), U5.10 (GND), U6.10 (GND), U7.10 (GND), U8.10 (GND)
unnamed: D1.2 (A), R1.1
unnamed: D1.1 (K), Q1.3 (E)
unnamed: D10.2 (A), D28.2 (A), D32.2 (A), D39.2 (A), D64.2 (A), D72.2 (A), D79.2 (A), D85.2 (A), D93.2 (A), D99.2 (A), D111.2 (A), D119.2 (A), D125.2 (A), D144.2 (A), D152.2 (A), D165.2 (A), RP1.2, U5.18 (D7)
unnamed: D11.2 (A), D14.2 (A), D16.2 (A), D20.2 (A), D21.2 (A), D24.2 (A), D26.2 (A), D31.2 (A), D34.2 (A), D35.2 (A), D38.2 (A), D41.2 (A), D175.2 (A), D181.2 (A), D188.2 (A), D231.2 (A), RP2.5, U6.4 (D1)
unnamed: D17.2 (A), D27.2 (A), D36.2 (A), D176.2 (A), D182.2 (A), D189.2 (A), D232.2 (A), D233.2 (A), D234.2 (A), D235.2 (A), D236.2 (A), D237.2 (A), D238.2 (A), D239.2 (A), D240.2 (A), D241.2 (A), RP2.6, U6.14 (D5)
unnamed: D43.1 (K), R3.2
unnamed: D44.1 (K), R4.2
unnamed: D45.1 (K), R5.2
unnamed: D46.1 (K), R6.2
unnamed: D47.2 (A), R7.2
unnamed: D48.1 (K), R8.2
unnamed: D49.1 (K), R9.2
unnamed: D50.1 (K), R10.2
unnamed: D51.1 (K), R11.2
unnamed: D52.1 (K), R12.2
unnamed: D53.1 (K), R13.2
unnamed: D54.1 (K), R14.2
unnamed: D55.1 (K), R15.2
unnamed: D56.1 (K), R16.2
unnamed: D57.1 (K), R17.2
unnamed: D58.1 (K), R18.2
unnamed: D59.1 (K), R19.2
unnamed: D60.1 (K), R20.2
unnamed: D61.1 (K), R21.2
unnamed: D62.1 (K), R22.2
unnamed: D63.1 (K), R23.2
unnamed: D7.2 (A), D65.2 (A), D73.2 (A), D86.2 (A), D94.2 (A), D100.2 (A), D106.2 (A), D112.2 (A), D120.2 (A), D126.2 (A), D132.2 (A), D137.2 (A), D145.2 (A), D153.2 (A), D159.2 (A), D166.2 (A), R2.2, RP1.3, U1.9 (~LOAD), U5.3 (D0)
unnamed: D3.2 (A), D8.2 (A), D12.2 (A), D22.2 (A), D37.2 (A), D40.2 (A), D66.2 (A), D87.2 (A), D101.2 (A), D107.2 (A), D113.2 (A), D127.2 (A), D133.2 (A), D138.2 (A), D146.2 (A), D167.2 (A), RP1.4, U5.17 (D6)
unnamed: D18.2 (A), D29.2 (A), D67.2 (A), D74.2 (A), D80.2 (A), D88.2 (A), D95.2 (A), D102.2 (A), D114.2 (A), D121.2 (A), D128.2 (A), D139.2 (A), D147.2 (A), D154.2 (A), D160.2 (A), D168.2 (A), RP1.5, U5.4 (D1)
unnamed: D25.2 (A), D69.2 (A), D76.2 (A), D82.2 (A), D90.2 (A), D97.2 (A), D103.2 (A), D109.2 (A), D116.2 (A), D123.2 (A), D135.2 (A), D141.2 (A), D149.2 (A), D156.2 (A), D162.2 (A), D170.2 (A), RP1.7, U5.7 (D2)
unnamed: D13.2 (A), D23.2 (A), D70.2 (A), D77.2 (A), D83.2 (A), D91.2 (A), D104.2 (A), D110.2 (A), D117.2 (A), D130.2 (A), D136.2 (A), D142.2 (A), D150.2 (A), D157.2 (A), D163.2 (A), D171.2 (A), RP1.8, U5.13 (D4)
unnamed: D19.2 (A), D30.2 (A), D71.2 (A), D78.2 (A), D84.2 (A), D92.2 (A), D98.2 (A), D105.2 (A), D118.2 (A), D124.2 (A), D131.2 (A), D143.2 (A), D151.2 (A), D158.2 (A), D164.2 (A), D172.2 (A), RP1.9, U5.8 (D3)
unnamed: D15.2 (A), D68.2 (A), D75.2 (A), D81.2 (A), D89.2 (A), D96.2 (A), D108.2 (A), D115.2 (A), D122.2 (A), D129.2 (A), D134.2 (A), D140.2 (A), D148.2 (A), D155.2 (A), D161.2 (A), D169.2 (A), RP1.6, U5.14 (D5)
unnamed: D33.2 (A), D173.2 (A), D180.2 (A), D186.2 (A), D193.2 (A), D194.2 (A), D195.2 (A), D196.2 (A), D197.2 (A), D198.2 (A), D199.2 (A), D200.2 (A), D201.2 (A), D202.2 (A), D203.2 (A), D204.2 (A), RP2.2, U6.18 (D7)
unnamed: D6.2 (A), D174.2 (A), D187.2 (A), D218.2 (A), D219.2 (A), D220.2 (A), D221.2 (A), D222.2 (A), D223.2 (A), D224.2 (A), D225.2 (A), D226.2 (A), D227.2 (A), D228.2 (A), D229.2 (A), D230.2 (A), RP2.4, U6.17 (D6)
unnamed: D42.2 (A), D177.2 (A), D183.2 (A), D190.2 (A), D242.2 (A), D243.2 (A), D244.2 (A), D245.2 (A), D246.2 (A), D247.2 (A), D248.2 (A), D249.2 (A), D250.2 (A), D251.2 (A), D252.2 (A), D253.2 (A), RP2.7, U6.7 (D2)
unnamed: D178.2 (A), D184.2 (A), D191.2 (A), D254.2 (A), D256.2 (A), D258.2 (A), D260.2 (A), D262.2 (A), D264.2 (A), D266.2 (A), D268.2 (A), D270.2 (A), D272.2 (A), D274.2 (A), D276.2 (A), D278.2 (A), RP2.8, U6.13 (D4)
unnamed: D179.2 (A), D185.2 (A), D192.2 (A), D255.2 (A), D257.2 (A), D259.2 (A), D261.2 (A), D263.2 (A), D265.2 (A), D267.2 (A), D269.2 (A), D271.2 (A), D273.2 (A), D275.2 (A), D277.2 (A), D279.2 (A), RP2.9, U6.8 (D3)
unnamed: D4.2 (A), D5.2 (A), D9.2 (A), D205.2 (A), D206.2 (A), D207.2 (A), D208.2 (A), D209.2 (A), D210.2 (A), D211.2 (A), D212.2 (A), D213.2 (A), D214.2 (A), D215.2 (A), D216.2 (A), D217.2 (A), RP2.3, U6.3 (D0)
unnamed: J1.1, U1.6 (D)
unnamed: J1.2, U1.5 (C)
unnamed: J1.3, U1.4 (B)
unnamed: J1.4, U1.3 (A)
unnamed: J5.1, U5.5 (O1), U7.6
unnamed: J5.2, U5.16 (O6), U7.7
unnamed: J6.2, U5.12 (O4), U7.3
unnamed: J6.3, U5.6 (O2), U7.4
unnamed: J6.4, U5.15 (O5), U7.5
unnamed: J7.1, U6.2 (O0), U8.8
unnamed: J7.2, U6.19 (O7), U8.9
unnamed: J8.1, U6.6 (O2), U8.4
unnamed: J8.2, U6.15 (O5), U8.5
unnamed: J8.3, U6.5 (O1), U8.6
unnamed: J9.1, U6.9 (O3), U8.2
unnamed: J9.2, U6.12 (O4), U8.3
unnamed: Q1.1 (B), R2.1
unnamed: R3.1, U4.3
unnamed: R4.1, U4.5
unnamed: R5.1, U4.7
unnamed: R6.1, U4.9
unnamed: R7.1, U4.18
unnamed: R8.1, U7.11
unnamed: R9.1, U7.12
unnamed: R10.1, U7.13
unnamed: R11.1, U7.14
unnamed: R12.1, U7.15
unnamed: R13.1, U7.16
unnamed: R14.1, U7.17
unnamed: R15.1, U7.18
unnamed: R16.1, U8.11
unnamed: R17.1, U8.12
unnamed: R18.1, U8.13
unnamed: R19.1, U8.14
unnamed: R20.1, U8.15
unnamed: R21.1, U8.16
unnamed: R22.1, U8.17
unnamed: R23.1, U8.18
unnamed: U1.14 (QA), U2.1 (A0), U3.1 (A0), U4.11
unnamed: U1.13 (QB), U2.2 (A1), U3.2 (A1), U4.13
unnamed: U1.12 (QC), U2.3 (A2), U3.3 (A2), U4.15
unnamed: U1.11 (QD), U2.4 (~E1), U3.6 (E3), U4.17
unnamed: U5.2 (O0), U7.8
VCC: C1.1, C2.1, C3.1, C4.1, C5.1, C6.1, C7.1, C8.1, C9.1, D2.1 (K), D43.2 (A), D44.2 (A), D45.2 (A), D46.2 (A), D48.2 (A), D49.2 (A), D50.2 (A), D51.2 (A), D52.2 (A), D53.2 (A), D54.2 (A), D55.2 (A), D56.2 (A), D57.2 (A), D58.2 (A), D59.2 (A), D60.2 (A), D61.2 (A), D62.2 (A), D63.2 (A), J2.2, R1.2, RP1.1, RP2.1, U1.7 (ENP), U1.10 (ENT), U1.16 (VCC), U2.6 (E3), U2.16 (VCC), U3.16 (VCC), U4.4, U4.6, U4.8, U4.20 (VCC), U5.20 (VCC), U6.20 (VCC), U7.20 (VCC), U8.20 (VCC)

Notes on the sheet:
Steuersignale
vom Befehlesdecoder
Mikroprogramm- zähler MPC

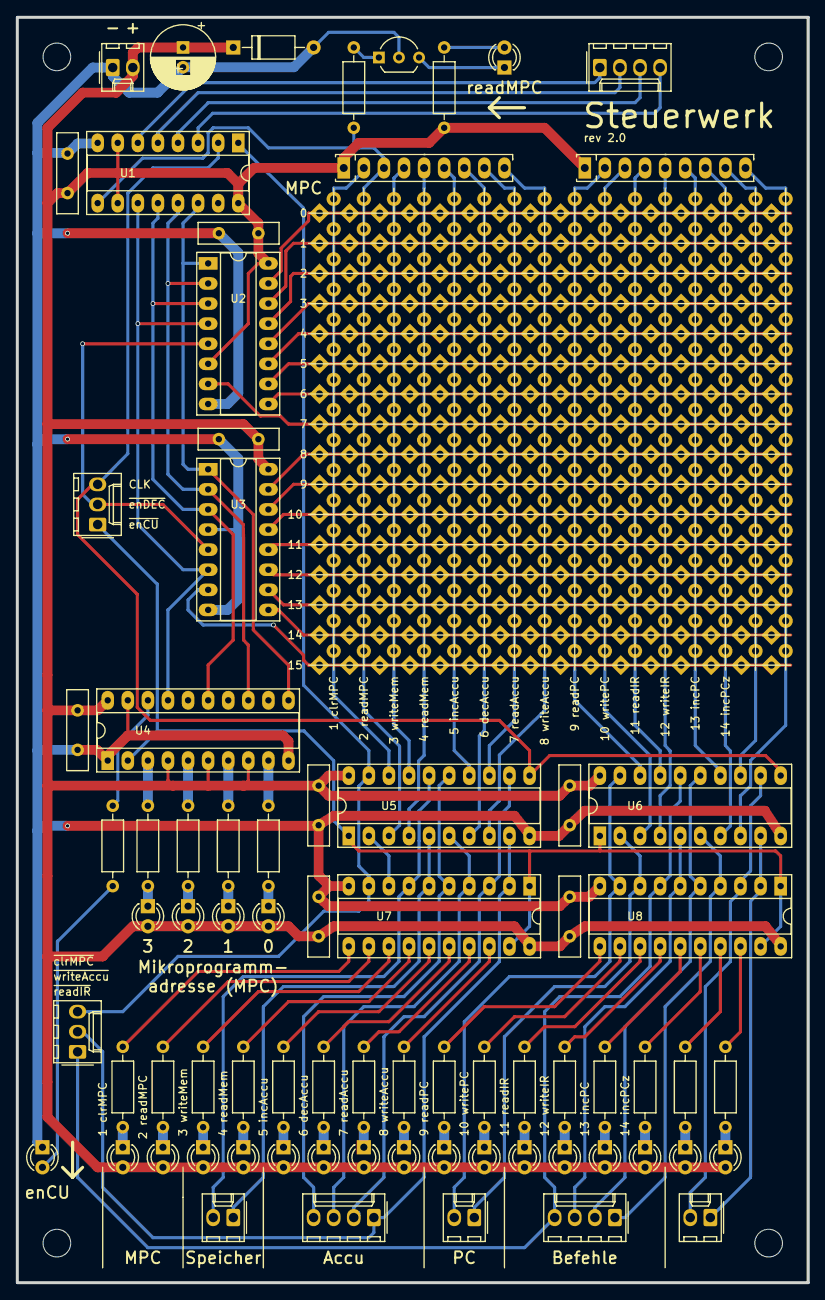
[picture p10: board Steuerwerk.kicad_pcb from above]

Board: 2 copper layers, 100.0 x 160.0 mm, 331 parts (0 on the bottom side), 106 nets.

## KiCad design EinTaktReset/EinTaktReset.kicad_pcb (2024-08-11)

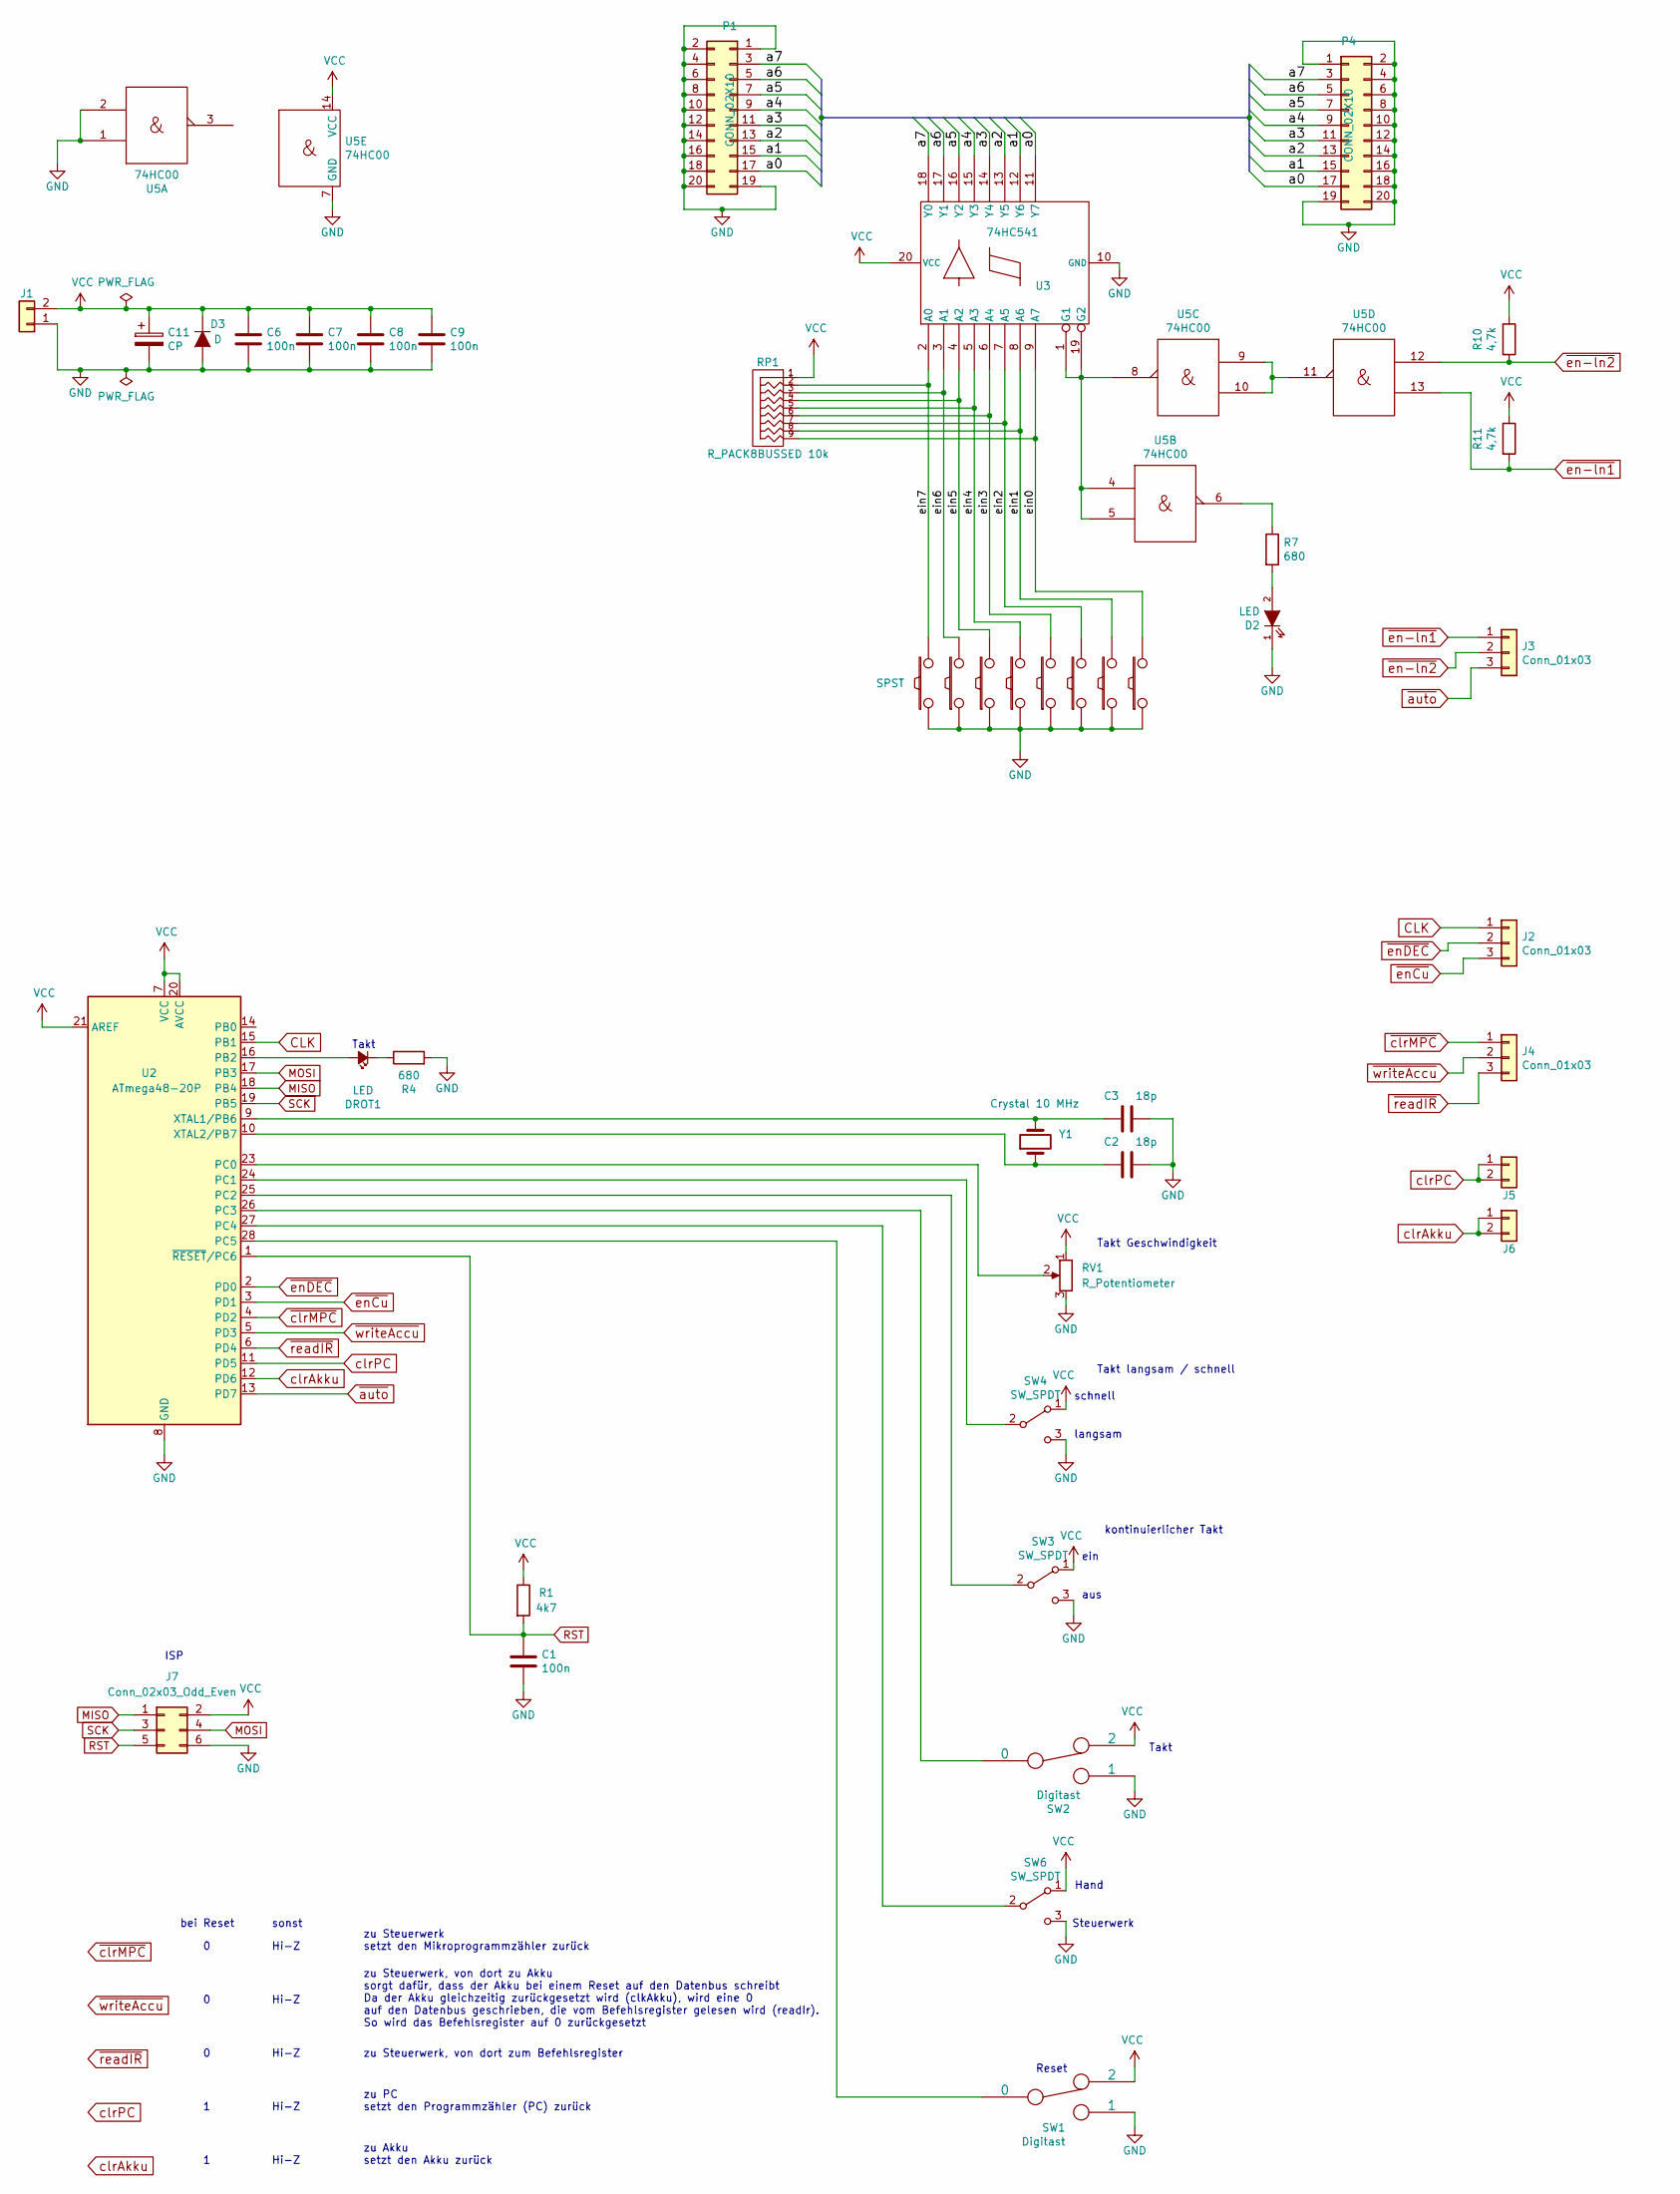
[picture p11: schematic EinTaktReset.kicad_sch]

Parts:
C1, C6, C7, C8, C9: 100n; C_Disc_D10.0mm_W2.5mm_P5.00mm
C2, C3: 18p; C_Disc_D3.8mm_W2.6mm_P2.50mm
C11: CP; CP_Radial_D8.0mm_P2.50mm
D2: LED; LED_D3.0mm
D3: D; D_A-405_P10.16mm_Horizontal
DROT1: LED; LED_D3.0mm
J1, J5, J6: Conn_01x02; Molex_KK-254_AE-6410-02A_1x02_P2.54mm_Vertical
J2, J3, J4: Conn_01x03; Molex_KK-254_AE-6410-03A_1x03_P2.54mm_Vertical
J7: Conn_02x03_Odd_Even; PinHeader_2x03_P2.54mm_Vertical
P1, P4: CONN_02X10; PinHeader_2x10_P2.54mm_Vertical
R1: 4k7; R_Axial_DIN0207_L6.3mm_D2.5mm_P10.16mm_Horizontal
R4, R7: 680; R_Axial_DIN0207_L6.3mm_D2.5mm_P10.16mm_Horizontal
R10, R11: 4,7k; R_Axial_DIN0207_L6.3mm_D2.5mm_P10.16mm_Horizontal
RP1: R_PACK8BUSSED 10k; R_Array_SIP9
RV1: R_Potentiometer; Potentiometer_Piher_PT-15-V02_Vertical
SW1, SW2: Digitast; Switch_Digitast
SW3, SW4, SW6: SW_SPDT; switch_100sp5
SW5, SW7, SW8, SW9, SW10, SW11, SW12, SW13: SPST; switch_100sp5
U2: ATmega48-20P; DIP-28_W7.62mm_LongPads
U3: 74HC541; DIP-20_W7.62mm_Socket_LongPads
U5: 74HC00; DIP-14_W7.62mm_Socket_LongPads
Y1: Crystal 10 MHz; Crystal_HC49-U_Vertical

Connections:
/a0: P1.17, P4.17, U3.11 (Y7)
/a1: P1.15, P4.15, U3.12 (Y6)
/a2: P1.13, P4.13, U3.13 (Y5)
/a3: P1.11, P4.11, U3.14 (Y4)
/a4: P1.9, P4.9, U3.15 (Y3)
/a5: P1.7, P4.7, U3.16 (Y2)
/a6: P1.5, P4.5, U3.17 (Y1)
/a7: P1.3, P4.3, U3.18 (Y0)
/ein0: RP1.9, SW13.2, U3.9 (A7)
/ein1: RP1.8, SW12.2, U3.8 (A6)
/ein2: RP1.7, SW11.2, U3.7 (A5)
/ein3: RP1.6, SW10.2, U3.6 (A4)
/ein4: RP1.5, SW9.2, U3.5 (A3)
/ein5: RP1.4, SW8.2, U3.4 (A2)
/ein6: RP1.3, SW7.2, U3.3 (A1)
/ein7: RP1.2, SW5.2, U3.2 (A0)
CLK: J2.1, U2.15 (PB1)
GND: C1.2, C2.2, C3.2, C6.2, C7.2, C8.2, C9.2, C11.2, D2.1 (K), D3.2 (A), J1.1, J7.6, P1.1, P1.2, P1.4, P1.6, P1.8, P1.10, P1.12, P1.14, P1.16, P1.18, P1.19, P1.20, P4.1, P4.2, P4.4, P4.6, P4.8, P4.10, P4.12, P4.14, P4.16, P4.18, P4.19, P4.20, R4.2, RV1.3, SW1.1, SW2.1, SW3.3 (C), SW4.3 (C), SW5.1, SW6.3 (C), SW7.1, SW8.1, SW9.1, SW10.1, SW11.1, SW12.1, SW13.1, U2.8 (GND), U2.22 (GND), U3.10 (GND), U5.1, U5.2, U5.7 (GND)
MISO: J7.1, U2.18 (PB4)
MOSI: J7.4, U2.17 (PB3)
unnamed: D2.2 (A), R7.2
unnamed: DROT1.2 (A), U2.16 (PB2)
unnamed: DROT1.1 (K), R4.1
unnamed: R7.1, U5.6
unnamed: SW3.2 (B), U2.25 (PC2)
unnamed: SW4.2 (B), U2.24 (PC1)
unnamed: SW6.2 (B), U2.27 (PC4)
unnamed: RV1.2, U2.23 (PC0)
unnamed: SW2.0, U2.26 (PC3)
unnamed: SW1.0, U2.28 (PC5)
unnamed: C3.1, U2.9 (XTAL1/PB6), Y1.2
unnamed: C2.1, U2.10 (XTAL2/PB7), Y1.1
unnamed: U3.1 (G1), U3.19 (G2), U5.4, U5.5, U5.8
unnamed: U5.9, U5.10, U5.11
RST: C1.1, J7.5, R1.2, U2.1 (~RESET/PC6)
SCK: J7.3, U2.19 (PB5)
VCC: C6.1, C7.1, C8.1, C9.1, C11.1, D3.1 (K), J1.2, J7.2, R1.1, R10.1, R11.1, RP1.1, RV1.1, SW1.2, SW2.2, SW3.1 (A), SW4.1 (A), SW6.1 (A), U2.7 (VCC), U2.20 (AVCC), U2.21 (AREF), U3.20 (VCC), U5.14 (VCC)
clrAkku: J6.1, J6.2, U2.12 (PD6)
clrPC: J5.1, J5.2, U2.11 (PD5)
~auto: J3.3, U2.13 (PD7)
~clrMPC: J4.1, U2.4 (PD2)
~en-ln1: J3.1, R11.2, U5.13
~en-ln2: J3.2, R10.2, U5.12
~enCu: J2.3, U2.3 (PD1)
~enDEC: J2.2, U2.2 (PD0)
~readIR: J4.3, U2.6 (PD4)
~writeAccu: J4.2, U2.5 (PD3)

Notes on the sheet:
Hand
Hi-Z
zu Steuerwerk, von dort zu Akku sorgt dafür, dass der Akku bei einem Reset auf den Datenbus schreibt Da der Akku gleichzeitig zurückgesetzt wird (clkAkku), wird eine 0 auf den Datenbus geschrieben, die vom Befehlsregister gelesen wird (readIr). So wird das Befehlsregister auf 0 zurückgesetzt
ein
zu PC setzt den Programmzähler (PC) zurück
langsam
bei Reset
zu Akku setzt den Akku zurück
Takt
Takt Geschwindigkeit
Takt langsam / schnell
aus
Steuerwerk
Reset
schnell
zu Steuerwerk, von dort zum Befehlsregister
kontinuierlicher Takt
zu Steuerwerk setzt den Mikroprogrammzähler zurück
ISP
sonst

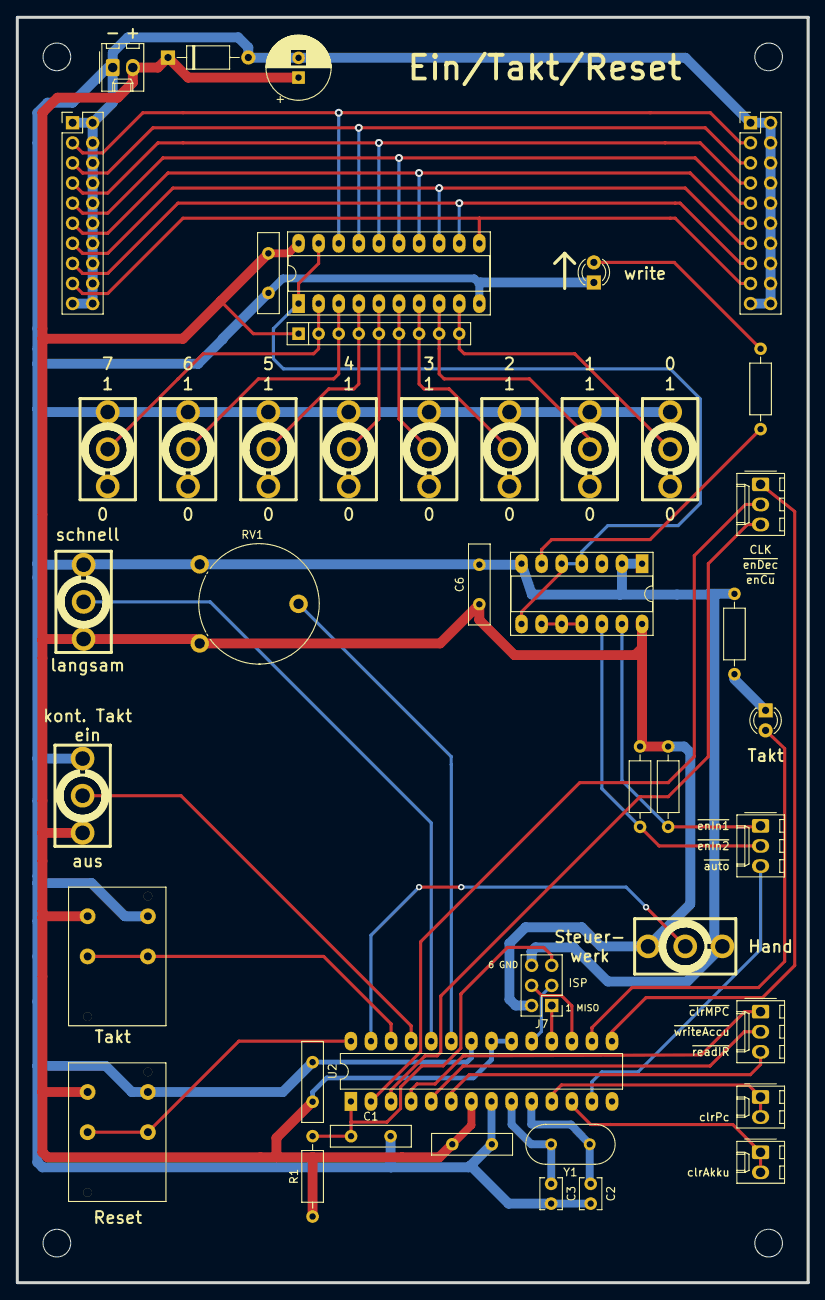
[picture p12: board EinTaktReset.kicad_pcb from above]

Board: 2 copper layers, 100.0 x 160.0 mm, 44 parts (0 on the bottom side), 47 nets.

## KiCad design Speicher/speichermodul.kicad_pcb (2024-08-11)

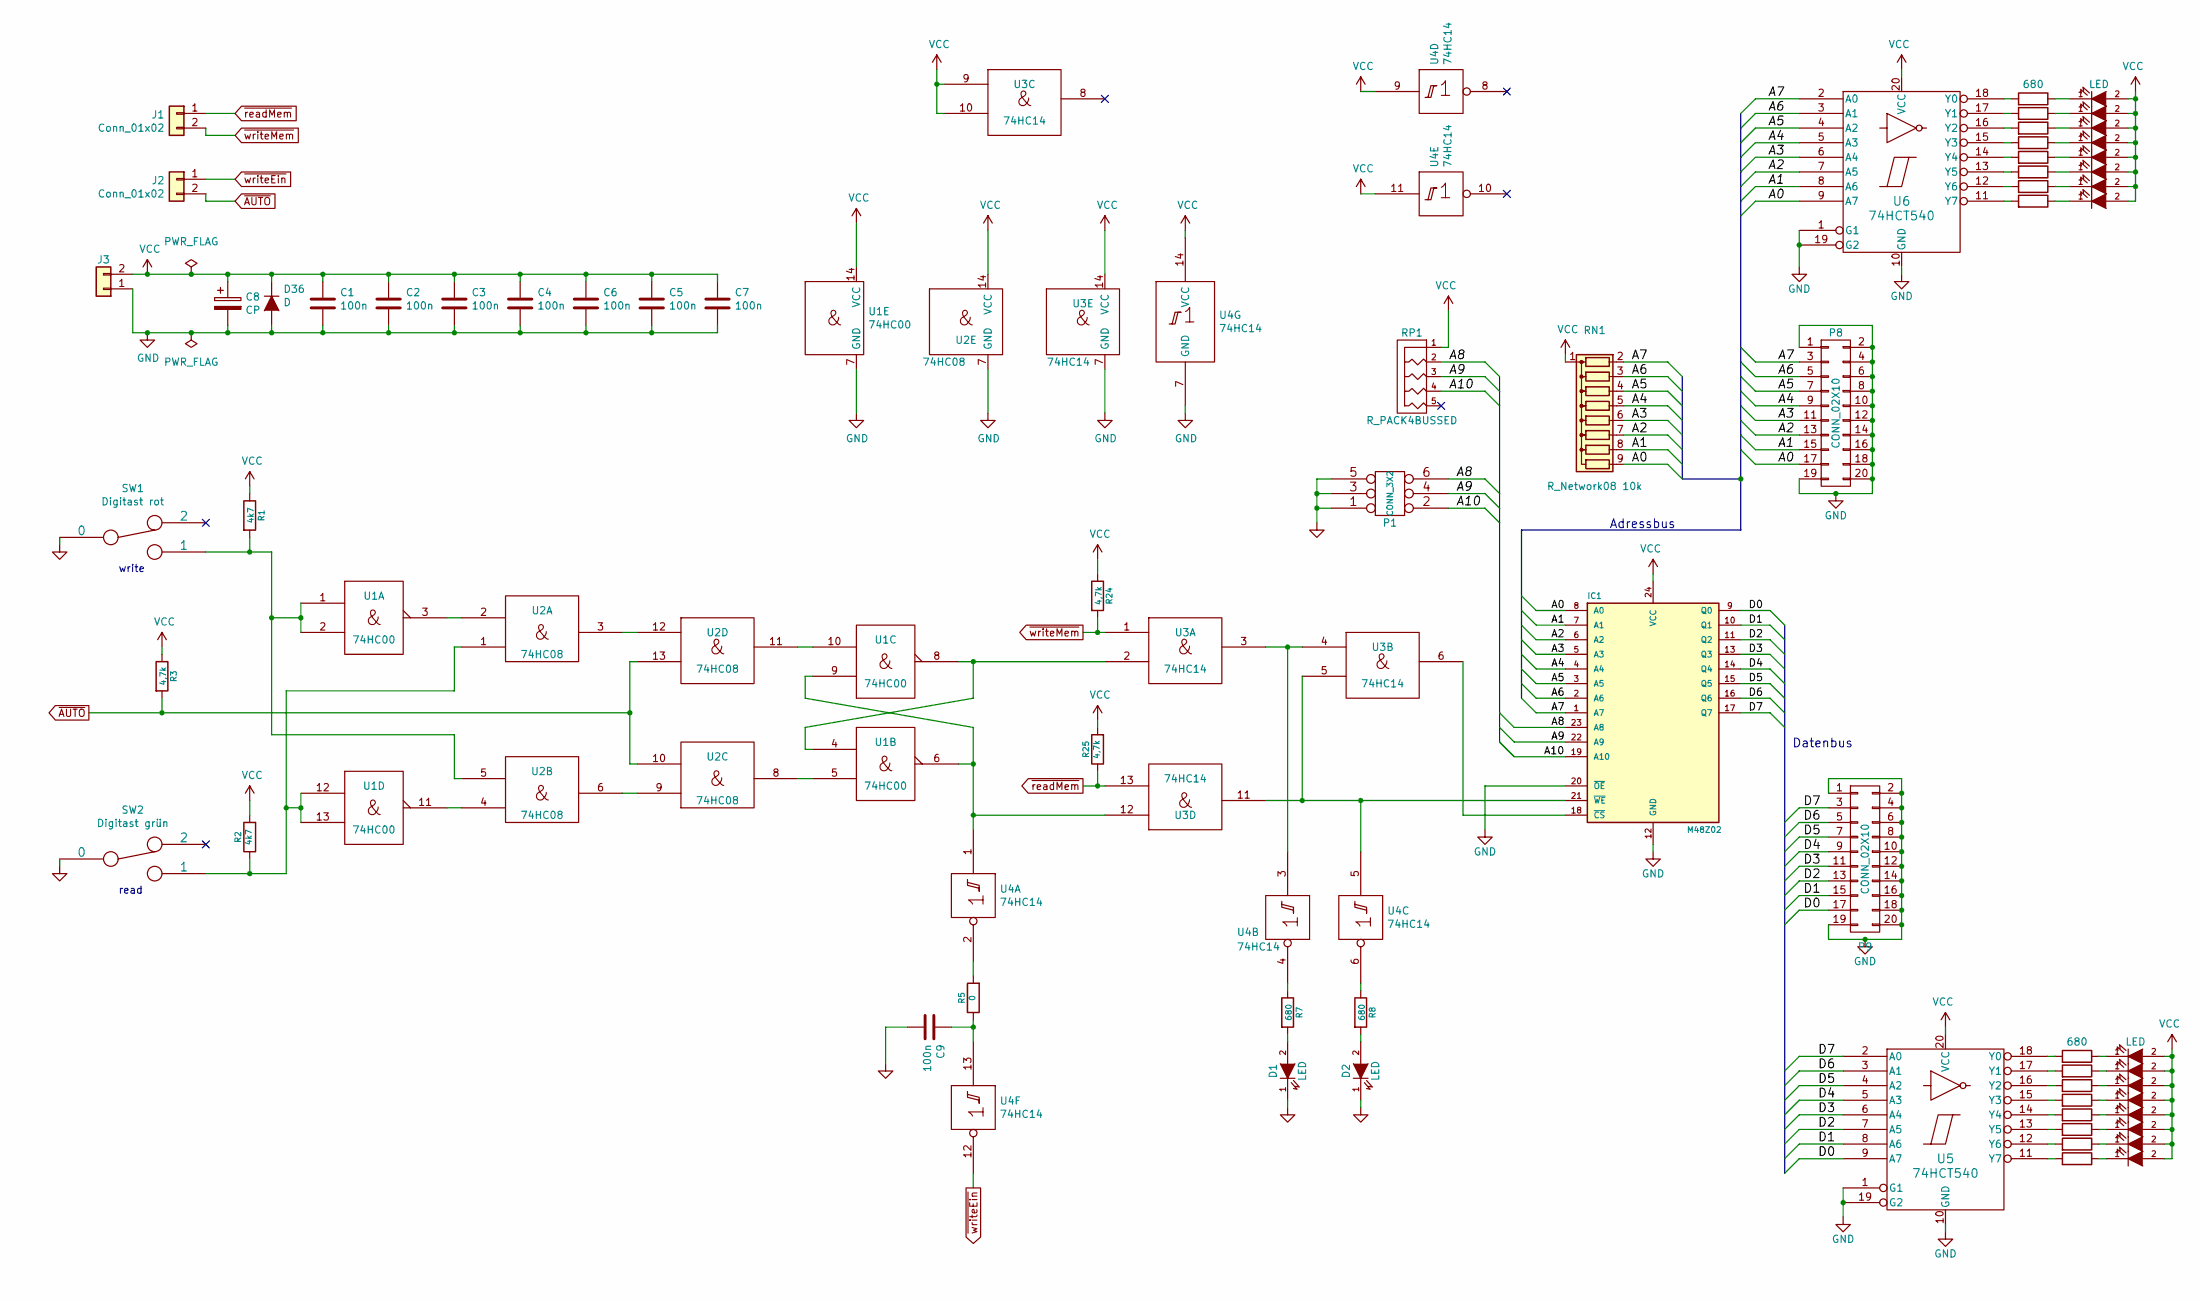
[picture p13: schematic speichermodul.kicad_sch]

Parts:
C1, C2, C3, C4, C5, C6, C7, C9: 100n; C_Disc_D10.0mm_W2.5mm_P5.00mm
C8: CP; CP_Radial_D8.0mm_P2.50mm
D1, D2, D3, D4, D5, D6, D7, D8, D9, D10, D11, D12, D13, D14, D15, D16, D17, D18: LED; LED_D3.0mm
D36: D; D_A-405_P10.16mm_Horizontal
IC1: M48Z02; DIP-24_W15.24mm_Socket_LongPads
J1, J2, J3: Conn_01x02; Molex_KK-254_AE-6410-02A_1x02_P2.54mm_Vertical
P1: CONN_3X2; PinHeader_2x03_P2.54mm_Vertical
P8, P9: CONN_02X10; PinHeader_2x10_P2.54mm_Vertical
R1, R2: 4k7; R_Axial_DIN0207_L6.3mm_D2.5mm_P10.16mm_Horizontal
R3, R24, R25: 4,7k; R_Axial_DIN0207_L6.3mm_D2.5mm_P10.16mm_Horizontal
R4, R7, R8, R9, R10, R11, R12, R13, R14, R15, R16, R17, R18, R19, R20, R21, R22, R23: 680; R_Axial_DIN0207_L6.3mm_D2.5mm_P10.16mm_Horizontal
R5: 0; R_Axial_DIN0207_L6.3mm_D2.5mm_P10.16mm_Horizontal
RN1: R_Network08 10k; R_Array_SIP9
RP1: R_PACK4BUSSED; R_Array_SIP5
SW1: Digitast rot; Switch_Digitast
SW2: Digitast grün; Switch_Digitast
U1: 74HC00; DIP-14_W7.62mm_Socket_LongPads
U2: 74HC08; DIP-14_W7.62mm_Socket_LongPads
U3, U4: 74HC14; DIP-14_W7.62mm_Socket_LongPads
U5, U6: 74HCT540; DIP-20_W7.62mm_Socket_LongPads

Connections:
/A0: IC1.8 (A0), P8.17, RN1.9 (R8), U6.9 (A7)
/A1: IC1.7 (A1), P8.15, RN1.8 (R7), U6.8 (A6)
/A2: IC1.6 (A2), P8.13, RN1.7 (R6), U6.7 (A5)
/A3: IC1.5 (A3), P8.11, RN1.6 (R5), U6.6 (A4)
/A4: IC1.4 (A4), P8.9, RN1.5 (R4), U6.5 (A3)
/A5: IC1.3 (A5), P8.7, RN1.4 (R3), U6.4 (A2)
/A6: IC1.2 (A6), P8.5, RN1.3 (R2), U6.3 (A1)
/A7: IC1.1 (A7), P8.3, RN1.2 (R1), U6.2 (A0)
/A8: IC1.23 (A8), P1.6, RP1.2
/A9: IC1.22 (A9), P1.4, RP1.3
/A10: IC1.19 (A10), P1.2, RP1.4
/D0: IC1.9 (Q0), P9.17, U5.9 (A7)
/D1: IC1.10 (Q1), P9.15, U5.8 (A6)
/D2: IC1.11 (Q2), P9.13, U5.7 (A5)
/D3: IC1.13 (Q3), P9.11, U5.6 (A4)
/D4: IC1.14 (Q4), P9.9, U5.5 (A3)
/D5: IC1.15 (Q5), P9.7, U5.4 (A2)
/D6: IC1.16 (Q6), P9.5, U5.3 (A1)
/D7: IC1.17 (Q7), P9.3, U5.2 (A0)
GND: C1.2, C2.2, C3.2, C4.2, C5.2, C6.2, C7.2, C8.2, C9.2, D1.1 (K), D2.1 (K), D36.2 (A), IC1.12 (GND), IC1.20 (~OE), J3.1, P1.1, P1.3, P1.5, P8.1, P8.2, P8.4, P8.6, P8.8, P8.10, P8.12, P8.14, P8.16, P8.18, P8.19, P8.20, P9.1, P9.2, P9.4, P9.6, P9.8, P9.10, P9.12, P9.14, P9.16, P9.18, P9.19, P9.20, SW1.0, SW2.0, U1.7 (GND), U2.7 (GND), U3.7 (GND), U4.7 (GND), U5.1 (G1), U5.10 (GND), U5.19 (G2), U6.1 (G1), U6.10 (GND), U6.19 (G2)
unnamed: C9.1, R5.1, U4.13
unnamed: D1.2 (A), R7.2
unnamed: D2.2 (A), R8.2
unnamed: D3.1 (K), R15.1
unnamed: D4.1 (K), R14.1
unnamed: D5.1 (K), R13.1
unnamed: D6.1 (K), R12.1
unnamed: D7.1 (K), R11.1
unnamed: D8.1 (K), R10.1
unnamed: D9.1 (K), R9.1
unnamed: D10.1 (K), R4.1
unnamed: D11.1 (K), R23.1
unnamed: D12.1 (K), R22.1
unnamed: D13.1 (K), R21.1
unnamed: D14.1 (K), R20.1
unnamed: D15.1 (K), R19.1
unnamed: D16.1 (K), R18.1
unnamed: D17.1 (K), R17.1
unnamed: D18.1 (K), R16.1
unnamed: IC1.18 (~CS), U3.6
unnamed: IC1.21 (~WE), U3.5, U3.11, U4.5
unnamed: R1.2, SW1.1, U1.1, U1.2, U2.5
unnamed: R2.1, SW2.1, U1.12, U1.13, U2.1
unnamed: R5.2, U4.2
unnamed: R7.1, U4.4
unnamed: R8.1, U4.6
unnamed: U1.3, U2.2
unnamed: U1.4, U1.8, U3.2
unnamed: U1.5, U2.8
unnamed: U1.6, U1.9, U3.12, U4.1
unnamed: U1.10, U2.11
unnamed: U1.11, U2.4
unnamed: U2.6, U2.9
unnamed: U2.3, U2.12
unnamed: U3.3, U3.4, U4.3
unnamed: R4.2, U5.18 (Y0)
unnamed: R9.2, U5.17 (Y1)
unnamed: R10.2, U5.16 (Y2)
unnamed: R11.2, U5.15 (Y3)
unnamed: R12.2, U5.14 (Y4)
unnamed: R13.2, U5.13 (Y5)
unnamed: R14.2, U5.12 (Y6)
unnamed: R15.2, U5.11 (Y7)
unnamed: R16.2, U6.18 (Y0)
unnamed: R17.2, U6.17 (Y1)
unnamed: R18.2, U6.16 (Y2)
unnamed: R19.2, U6.15 (Y3)
unnamed: R20.2, U6.14 (Y4)
unnamed: R21.2, U6.13 (Y5)
unnamed: R22.2, U6.12 (Y6)
unnamed: R23.2, U6.11 (Y7)
VCC: C1.1, C2.1, C3.1, C4.1, C5.1, C6.1, C7.1, C8.1, D3.2 (A), D4.2 (A), D5.2 (A), D6.2 (A), D7.2 (A), D8.2 (A), D9.2 (A), D10.2 (A), D11.2 (A), D12.2 (A), D13.2 (A), D14.2 (A), D15.2 (A), D16.2 (A), D17.2 (A), D18.2 (A), D36.1 (K), IC1.24 (VCC), J3.2, R1.1, R2.2, R3.1, R24.1, R25.2, RN1.1 (common), RP1.1, U1.14 (VCC), U2.14 (VCC), U3.9, U3.10, U3.14 (VCC), U4.9, U4.11, U4.14 (VCC), U5.20 (VCC), U6.20 (VCC)
~AUTO: J2.2, R3.2, U2.10, U2.13
~readMem: J1.1, R25.1, U3.13
~writeEin: J2.1, U4.12
~writeMem: J1.2, R24.2, U3.1

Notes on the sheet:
Adressbus
Datenbus
read
write

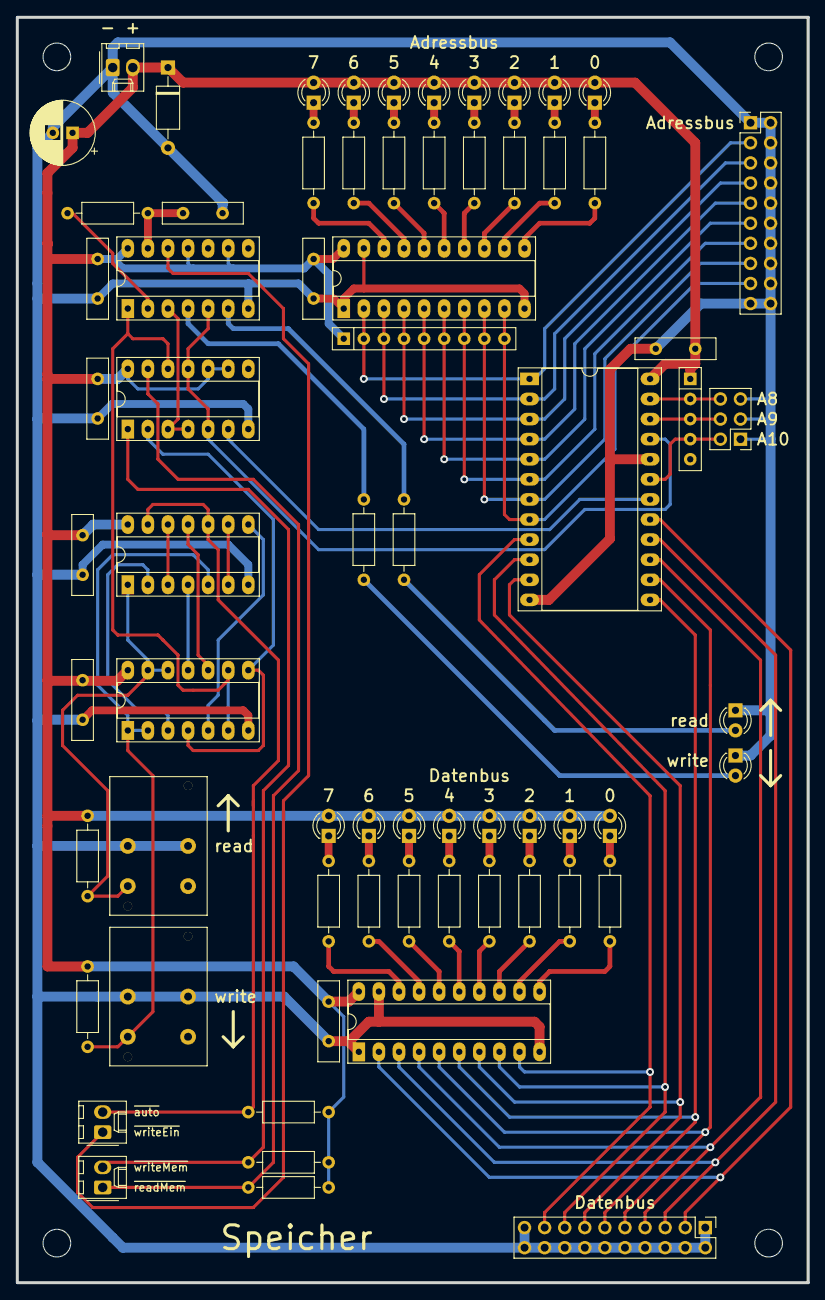
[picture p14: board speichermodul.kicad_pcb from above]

Board: 2 copper layers, 100.0 x 160.0 mm, 69 parts (0 on the bottom side), 76 nets.

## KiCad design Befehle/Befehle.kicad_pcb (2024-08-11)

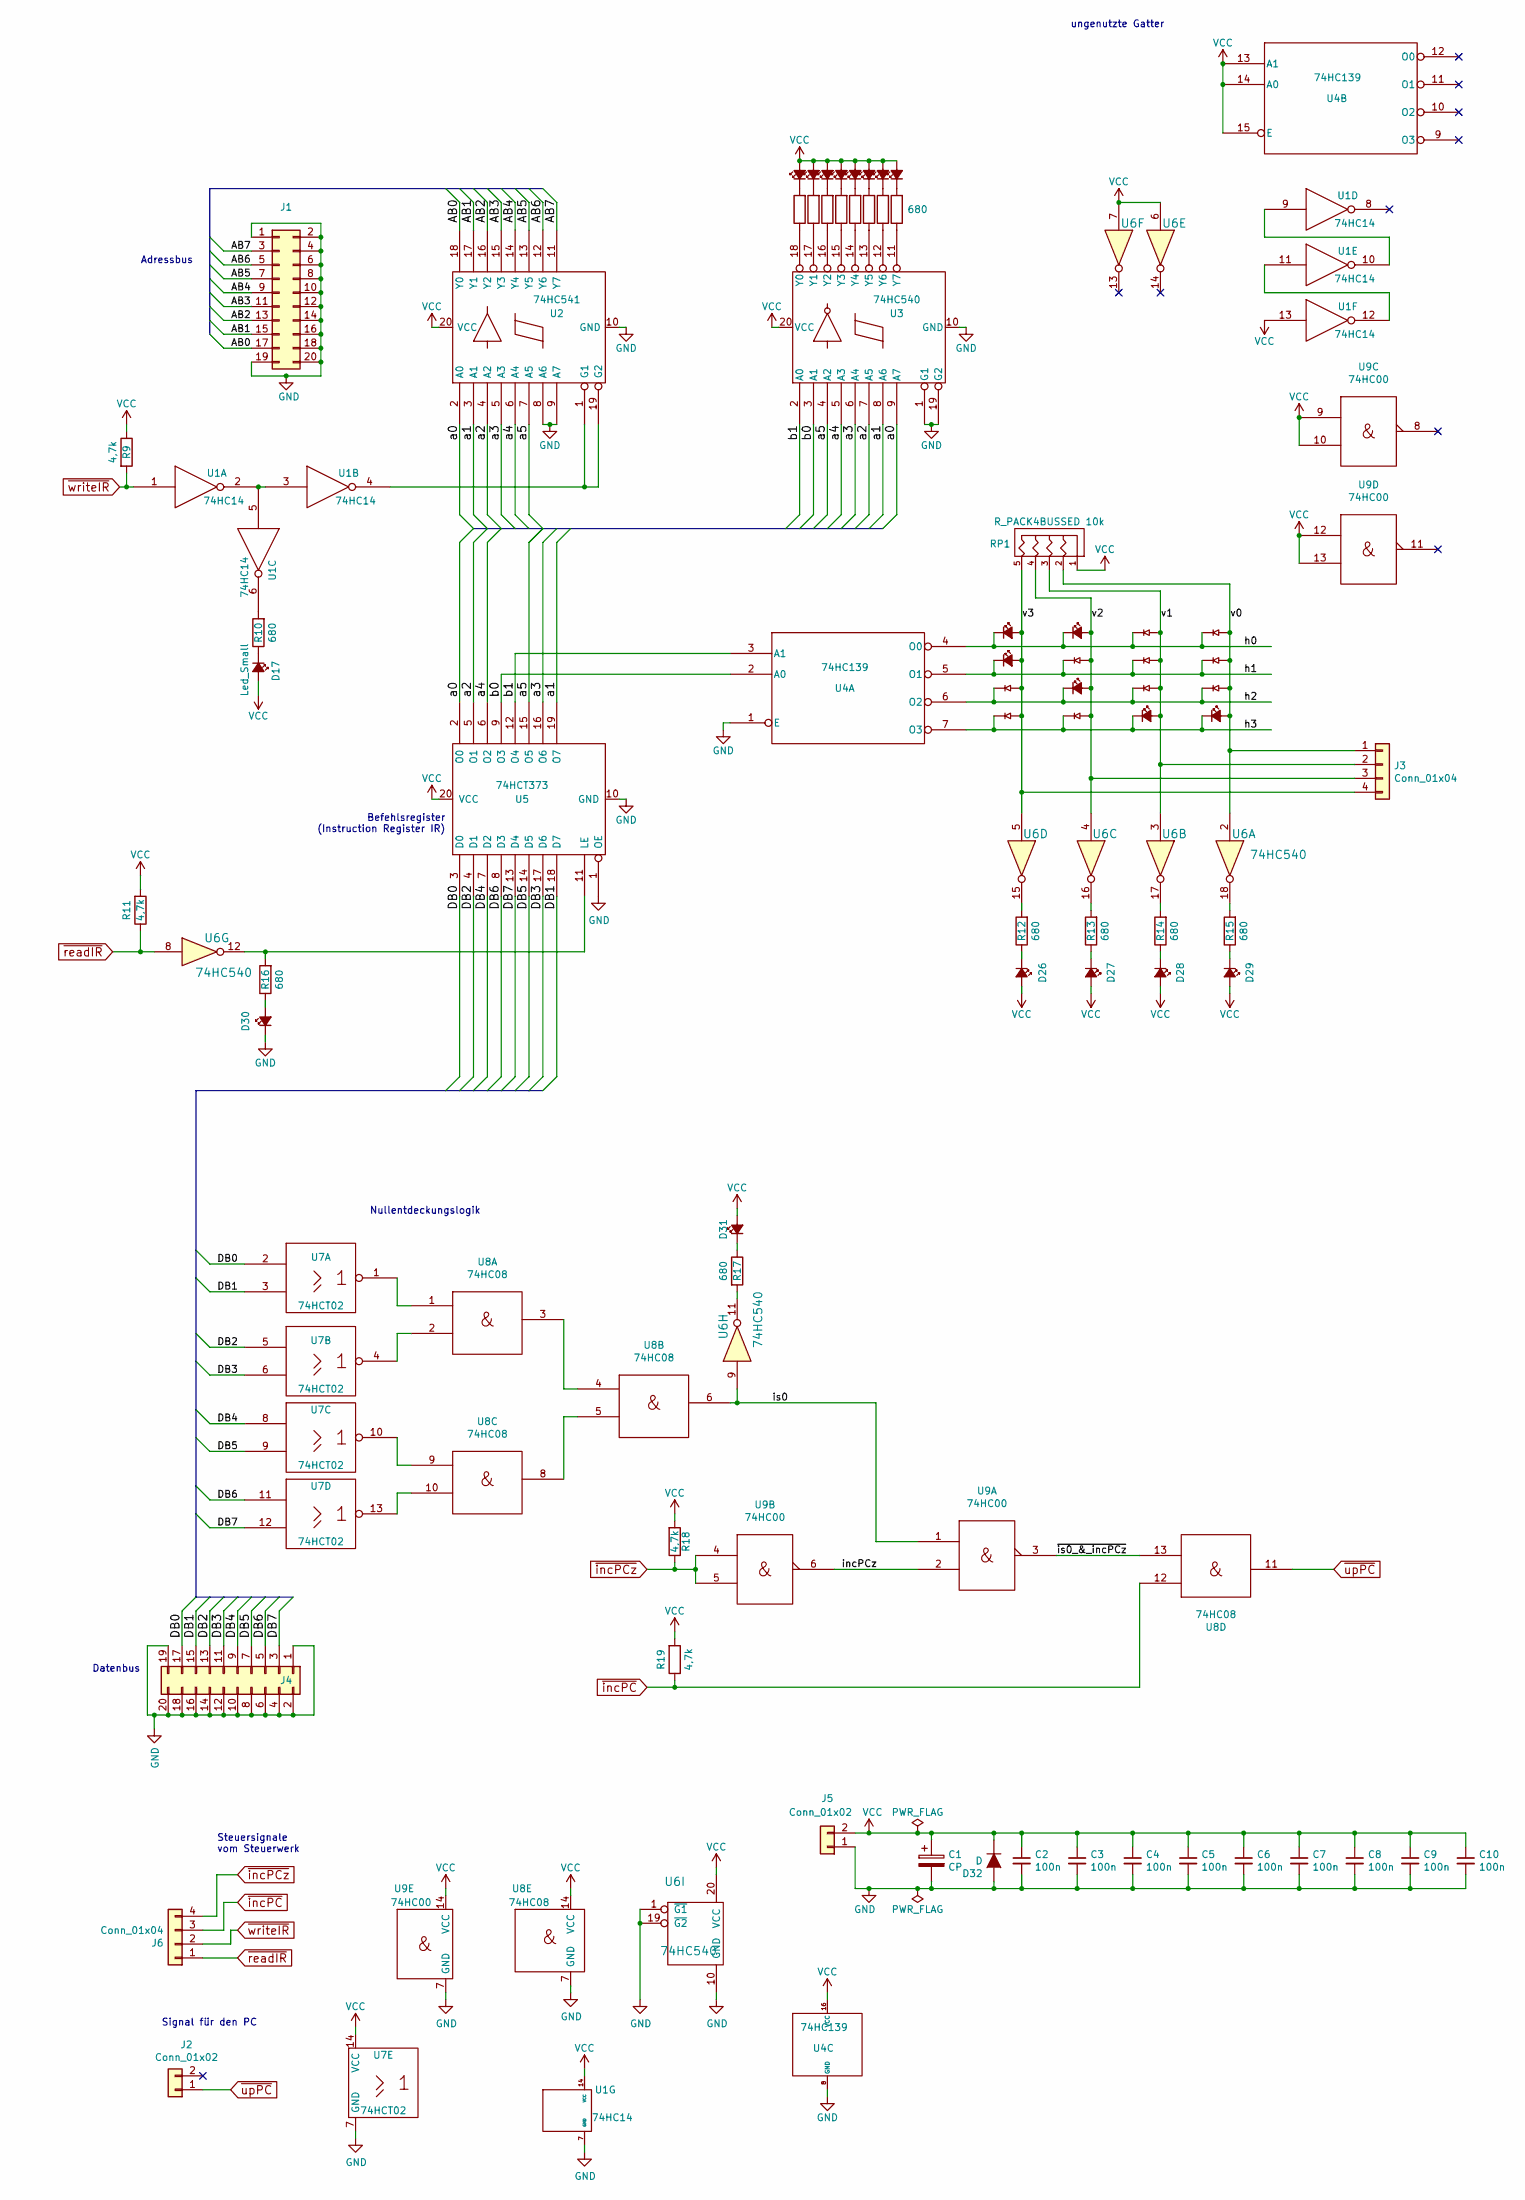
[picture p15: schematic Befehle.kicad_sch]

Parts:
C1: CP; CP_Radial_D8.0mm_P2.50mm
C2, C3, C4, C5, C6, C7, C8, C9, C10: 100n; C_Disc_D10.0mm_W2.5mm_P5.00mm
D1, D2, D3, D4, D5, D6, D7, D17: Led_Small; LED_D3.0mm
D8, D26, D27, D28, D29, D30, D31: LED; LED_D3.0mm
D9, D10, D13, D19, D24, D25: Led_Small; LED_Diodenmatrix
D11, D12, D14, D15, D16, D18, D20, D21, D22, D23: bonsai_Led_Small_Platzhalter; LED_Diodenmatrix_Platzhalter
D32: D; D_A-405_P10.16mm_Horizontal
J1, J4: Conn_02x10_Odd_Even; PinHeader_2x10_P2.54mm_Vertical
J2, J5: Conn_01x02; Molex_KK-254_AE-6410-02A_1x02_P2.54mm_Vertical
J3, J6: Conn_01x04; Molex_KK-254_AE-6410-04A_1x04_P2.54mm_Vertical
R1, R2, R3, R4, R5, R6, R7, R8, R10, R12, R13, R14, R15, R16, R17: 680; R_Axial_DIN0207_L6.3mm_D2.5mm_P10.16mm_Horizontal
R9, R11, R18, R19: 4,7k; R_Axial_DIN0207_L6.3mm_D2.5mm_P10.16mm_Horizontal
RP1: R_PACK4BUSSED 10k; R_Array_SIP5
U1: 74HC14; DIP-14_W7.62mm_Socket_LongPads
U2: 74HC541; DIP-20_W7.62mm_Socket_LongPads
U3, U6: 74HC540; DIP-20_W7.62mm_Socket_LongPads
U4: 74HC139; DIP-16_W7.62mm_Socket_LongPads
U5: 74HCT373; DIP-20_W7.62mm_Socket_LongPads
U7: 74HCT02; DIP-14_W7.62mm_Socket_LongPads
U8: 74HC08; DIP-14_W7.62mm_Socket_LongPads
U9: 74HC00; DIP-14_W7.62mm_Socket_LongPads

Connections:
/AB0: J1.17, U2.18 (Y0)
/AB1: J1.15, U2.17 (Y1)
/AB2: J1.13, U2.16 (Y2)
/AB3: J1.11, U2.15 (Y3)
/AB4: J1.9, U2.14 (Y4)
/AB5: J1.7, U2.13 (Y5)
/AB6: J1.5, U2.12 (Y6)
/AB7: J1.3, U2.11 (Y7)
/DB0: J4.17, U5.3 (D0), U7.2
/DB1: J4.15, U5.18 (D7), U7.3
/DB2: J4.13, U5.4 (D1), U7.5
/DB3: J4.11, U5.17 (D6), U7.6
/DB4: J4.9, U5.7 (D2), U7.8
/DB5: J4.7, U5.14 (D5), U7.9
/DB6: J4.5, U5.8 (D3), U7.11
/DB7: J4.3, U5.13 (D4), U7.12
/a0: U2.2 (A0), U3.9 (A7), U5.2 (O0)
/a1: U2.3 (A1), U3.8 (A6), U5.19 (O7)
/a2: U2.4 (A2), U3.7 (A5), U5.5 (O1)
/a3: U2.5 (A3), U3.6 (A4), U5.16 (O6)
/a4: U2.6 (A4), U3.5 (A3), U5.6 (O2)
/a5: U2.7 (A5), U3.4 (A2), U5.15 (O5)
/b0: U3.3 (A1), U4.2 (A0), U5.9 (O3)
/b1: U3.2 (A0), U4.3 (A1), U5.12 (O4)
/h0: D9.1 (K), D10.1 (K), D11.1 (K), D12.1 (K), U4.4 (O0)
/h1: D13.1 (K), D14.1 (K), D15.1 (K), D16.1 (K), U4.5 (O1)
/h2: D18.1 (K), D19.1 (K), D20.1 (K), D21.1 (K), U4.6 (O2)
/h3: D22.1 (K), D23.1 (K), D24.1 (K), D25.1 (K), U4.7 (O3)
/incPCz: U9.2, U9.6
/is0: U6.9, U8.6, U9.1
/v0: D12.2 (A), D16.2 (A), D21.2 (A), D25.2 (A), J3.1, RP1.2, U6.2
/v1: D11.2 (A), D15.2 (A), D20.2 (A), D24.2 (A), J3.2, RP1.3, U6.3
/v2: D10.2 (A), D14.2 (A), D19.2 (A), D23.2 (A), J3.3, RP1.4, U6.4
/v3: D9.2 (A), D13.2 (A), D18.2 (A), D22.2 (A), J3.4, RP1.5, U6.5
/~is0_&_incPCz: U8.13, U9.3
GND: C1.2, C2.2, C3.2, C4.2, C5.2, C6.2, C7.2, C8.2, C9.2, C10.2, D30.1 (K), D32.2 (A), J1.1, J1.2, J1.4, J1.6, J1.8, J1.10, J1.12, J1.14, J1.16, J1.18, J1.19, J1.20, J4.1, J4.2, J4.4, J4.6, J4.8, J4.10, J4.12, J4.14, J4.16, J4.18, J4.19, J4.20, J5.1, U1.7 (GND), U2.8 (A6), U2.9 (A7), U2.10 (GND), U3.1 (G1), U3.10 (GND), U3.19 (G2), U4.1 (E), U4.8 (GND), U5.1 (OE), U5.10 (GND), U6.1 (~G1), U6.10 (GND), U6.19 (~G2), U7.7 (GND), U8.7 (GND), U9.7 (GND)
unnamed: D1.1 (K), R1.2
unnamed: D2.1 (K), R2.2
unnamed: D3.1 (K), R3.2
unnamed: D4.1 (K), R4.2
unnamed: D5.1 (K), R5.2
unnamed: D6.1 (K), R6.2
unnamed: D7.1 (K), R7.2
unnamed: D8.1 (K), R8.2
unnamed: D17.1 (K), R10.1
unnamed: D26.1 (K), R12.1
unnamed: D27.1 (K), R13.1
unnamed: D28.1 (K), R14.1
unnamed: D29.1 (K), R15.1
unnamed: D30.2 (A), R16.1
unnamed: D31.1 (K), R17.1
unnamed: R10.2, U1.6
unnamed: R12.2, U6.15
unnamed: R13.2, U6.16
unnamed: R14.2, U6.17
unnamed: R15.2, U6.18
unnamed: R17.2, U6.11
unnamed: U1.2, U1.3, U1.5
unnamed: U1.9, U1.10
unnamed: U1.11, U1.12
unnamed: U1.4, U2.1 (G1), U2.19 (G2)
unnamed: R1.1, U3.18 (Y0)
unnamed: R2.1, U3.17 (Y1)
unnamed: R3.1, U3.16 (Y2)
unnamed: R4.1, U3.15 (Y3)
unnamed: R5.1, U3.14 (Y4)
unnamed: R6.1, U3.13 (Y5)
unnamed: R7.1, U3.12 (Y6)
unnamed: R8.1, U3.11 (Y7)
unnamed: R16.2, U5.11 (LE), U6.12
unnamed: U7.1, U8.1
unnamed: U7.4, U8.2
unnamed: U7.10, U8.9
unnamed: U7.13, U8.10
unnamed: U8.3, U8.4
unnamed: U8.5, U8.8
VCC: C1.1, C2.1, C3.1, C4.1, C5.1, C6.1, C7.1, C8.1, C9.1, C10.1, D1.2 (A), D2.2 (A), D3.2 (A), D4.2 (A), D5.2 (A), D6.2 (A), D7.2 (A), D8.2 (A), D17.2 (A), D26.2 (A), D27.2 (A), D28.2 (A), D29.2 (A), D31.2 (A), D32.1 (K), J5.2, R9.1, R11.2, R18.2, R19.2, RP1.1, U1.13, U1.14 (VCC), U2.20 (VCC), U3.20 (VCC), U4.13 (A1), U4.14 (A0), U4.15 (E), U4.16 (VCC), U5.20 (VCC), U6.6, U6.7, U6.20 (VCC), U7.14 (VCC), U8.14 (VCC), U9.9, U9.10, U9.12, U9.13, U9.14 (VCC)
~incPCz: J6.4, R18.1, U9.4, U9.5
~incPC: J6.3, R19.1, U8.12
~readIR: J6.1, R11.1, U6.8
~upPC: J2.1, U8.11
~writeIR: J6.2, R9.2, U1.1

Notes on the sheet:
Befehlsregister (Instruction Register IR)
Nullentdeckungslogik
ungenutzte Gatter
Steuersignale vom Steuerwerk
Signal für den PC
Adressbus
Datenbus

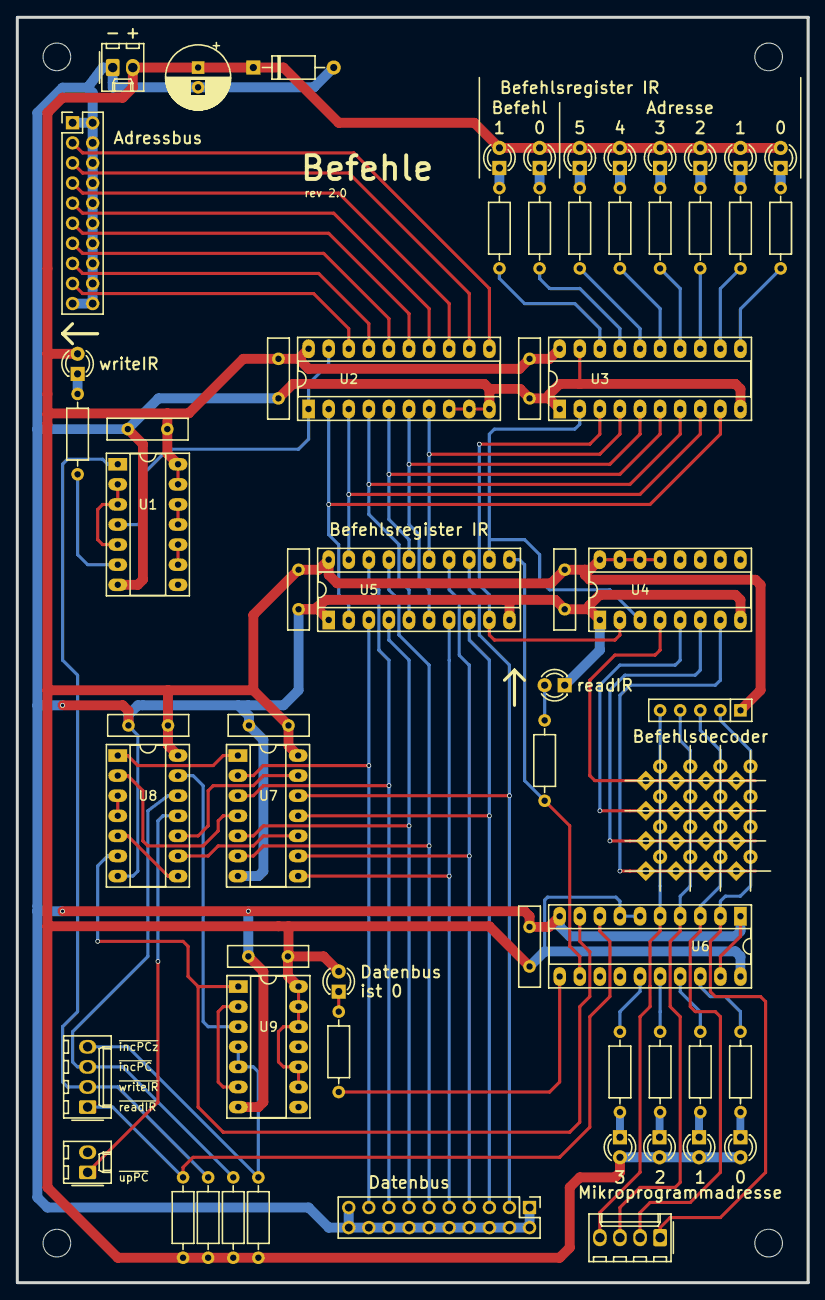
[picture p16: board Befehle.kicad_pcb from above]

Board: 2 copper layers, 100.0 x 160.0 mm, 77 parts (0 on the bottom side), 82 nets.

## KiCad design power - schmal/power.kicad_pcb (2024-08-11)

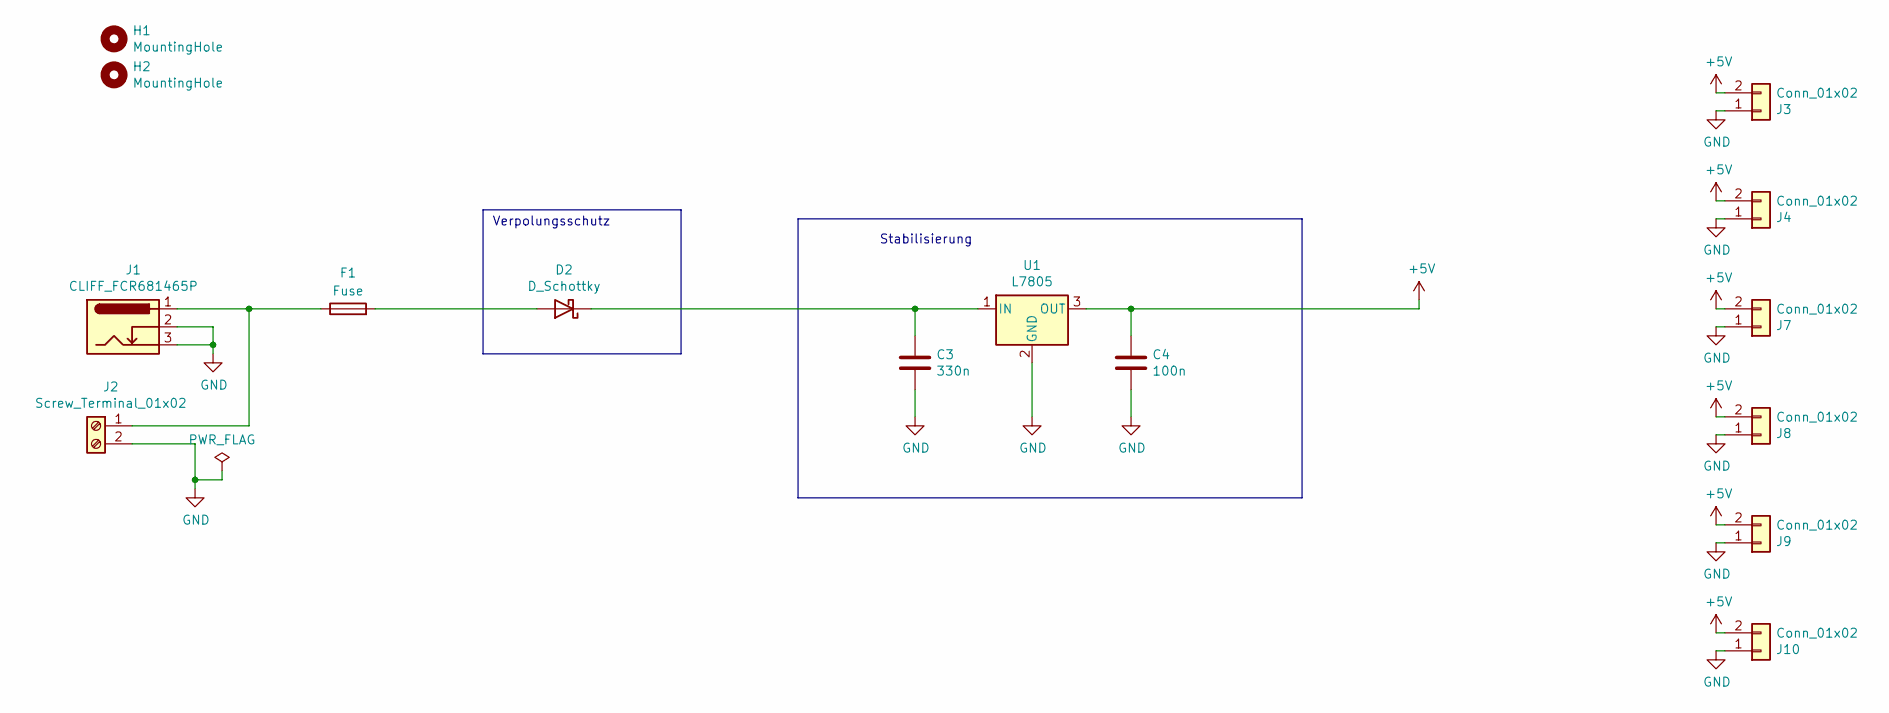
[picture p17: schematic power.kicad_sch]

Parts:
C3: 330n; C_Rect_L7.2mm_W2.2mm_P2.54mm_P5.08mm
C4: 100n; C_Rect_L7.2mm_W2.2mm_P2.54mm_P5.08mm
D2: D_Schottky; D_DO-201AE_P12.70mm_Horizontal
F1: Fuse; Sicherungshalter
H1, H2: MountingHole; MountingHole_3.5mm
J1: CLIFF_FCR681465P
J2: Screw_Terminal_01x02; TerminalBlock_Phoenix_MKDS-1,5-2-5.08_1x02_P5.08mm_Horizont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
J3, J4, J7, J8, J9, J10: Conn_01x02; Molex_KK-254_AE-6410-02A_1x02_P2.54mm_Vertical
U1: L7805; TO-220-3_Vertical

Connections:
+5V: C4.1, J3.2, J4.2, J7.2, J8.2, J9.2, J10.2, U1.3 (OUT)
GND: C3.2, C4.2, J1.2, J1.3, J2.2, J3.1, J4.1, J7.1, J8.1, J9.1, J10.1, U1.2 (GND)
unnamed: D2.2 (A), F1.2
unnamed: C3.1, D2.1 (K), U1.1 (IN)
unnamed: F1.1, J1.1, J2.1

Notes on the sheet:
Verpolungsschutz
Stabilisierung

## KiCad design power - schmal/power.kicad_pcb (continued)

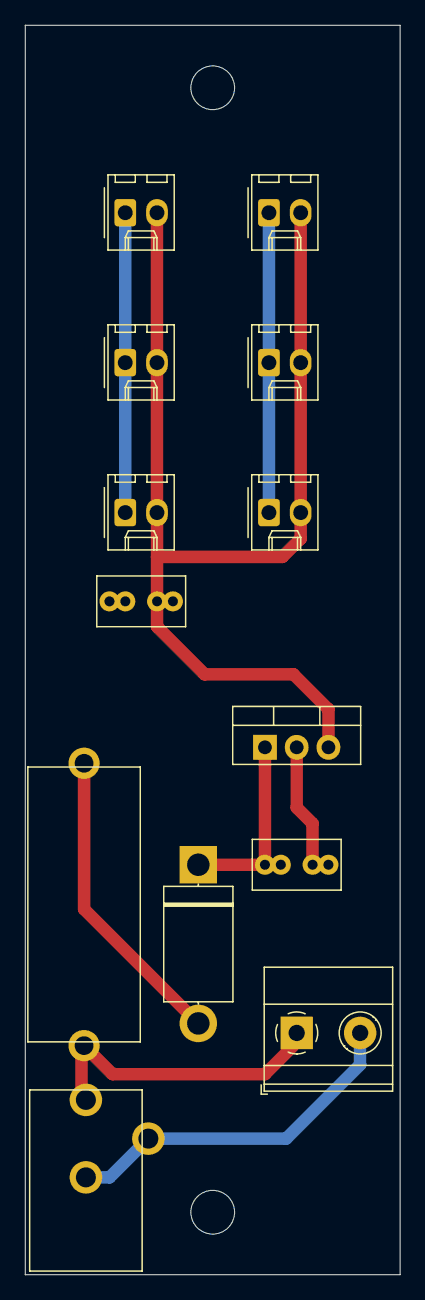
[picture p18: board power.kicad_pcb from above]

Board: 2 copper layers, 30.0 x 100.0 mm, 15 parts (0 on the bottom side), 5 nets.

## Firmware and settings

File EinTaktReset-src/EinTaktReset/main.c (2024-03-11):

/*
 * EinTaktReset.c
 *
 * Created: 23.06.2023 16:48:30
 * Author : Michael
 */ 

#include <avr/io.h>
#include <avr/interrupt.h>
#include <stdbool.h>

#include "board.h"

#define F_CPU 1000000UL  // 1 MHz
#include <util/delay.h>

struct debounce_state
{
	uint8_t debounced_state;
	uint8_t counter;
	uint8_t changeDetected;
};


typedef struct debounce_state Debounce_state;

volatile Debounce_state CLK_Speed_debounce_state;
volatile Debounce_state CLK_auto_ON_OFF_debounce_state;
volatile Debounce_state CLK_manual_debounce_state;
volatile Debounce_state CU_ON_OFF_debounce_state;
volatile Debounce_state RESET_debounce_state;



void debounce(volatile Debounce_state *state, uint8_t pin)
{
	uint8_t valueNow = GET_PIN(PINC, pin);

	if (valueNow != state->debounced_state)
	{
		state->counter ++;
		if (state->counter >= 1)
		{
			state->counter = 0;
			state->changeDetected = 1;
			state->debounced_state = valueNow;
		}
		} else {
		state->counter = 0;
	}
}

void debounce_all()
{
	debounce(&CLK_Speed_debounce_state, CLK_Speed);
	debounce(&CLK_auto_ON_OFF_debounce_state, CLK_auto_ON_OFF);
	debounce(&CLK_manual_debounce_state, CLK_manual);
	debounce(&CU_ON_OFF_debounce_state, CU_ON_OFF);
	debounce(&RESET_debounce_state, RESET);
}


void init_bonsai()
{
	
}

void starte_automatischen_takt()
{
	if (TCCR1B & ((1 << CS12) | (1 << CS11) | (1 << CS10))) {
		// Der Timer läuft bereits
	} else {
		// Der Timer läuft nicht
		// Timer starten
		if (CLK_Speed_debounce_state.debounced_state) {
			// schnell
			OCR1A = 5;
			} else {
			// langsam
			OCR1A = 1000;
		}
		
		TCNT1 = 0;
		TCCR1B |= (1 << CS12) | (1 << CS10);
	}
}

void stoppe_automatischen_takt()
{
	TCCR1B &= ~(1 << CS12 |1 << CS11 | 1 << CS10);
	//PORTB &= ~((1 << CLK_PIN) | (1 << CLK_LED_PIN));
}

// ca. f = 1kHz
// ISR (TIMER0_COMPA_vect)
void tick_loop()
{
	//debounce(&CLK_Speed_debounce_state, CLK_Speed);
	//debounce(&CLK_auto_ON_OFF_debounce_state, CLK_auto_ON_OFF);
	//debounce(&CLK_manual_debounce_state, CLK_manual);
	//debounce(&CU_ON_OFF_debounce_state, CU_ON_OFF);
	//debounce(&RESET_debounce_state, RESET);
	debounce_all();
	
	if (RESET_debounce_state.debounced_state == 0)
	{
		// Reset-Button ist im Moment gedrückt
		stoppe_automatischen_takt();
		
		// Signale in den Reset-Zustand bringen
		// Pins konfigurieren
		// DDR: 0: Eingang
		//      1: Ausgang


				
		PORTD &= ~( (1 << _CLR_MPC) | (1 << _WRITE_ACCU) | (1 << _READ_IR) );

		PORTD |= (1 << CLR_PC) | (1 << CLR_AKKU) | (1 << _EN_DEC) | (1 << _EN_CU);	

		DDRD |= (1 << _CLR_MPC) | (1 << _WRITE_ACCU) | (1 << _READ_IR) | (1 << CLR_PC) | (1 << CLR_AKKU);
		
		// Takt einschalten, damit die FlipFlops im Steuerwerk zurückgesetzt werden
		PORTB |= (1 << CLK_PIN) | (1 << CLK_LED_PIN);
				
		// Abarbeitung der ISR abbrechen
		return;
	}
	
	// der Reset-Button ist im Moment nicht gedrückt
	// Signale aus dem Reset-Zustand herausnehmen
	DDRD &= ~((1 << _CLR_MPC) | (1 << _WRITE_ACCU) | (1 << _READ_IR) | (1 << CLR_PC) | (1 << CLR_AKKU));
	// Pull-Ups abschalten
	PORTD &= ~( (1 << _CLR_MPC) | (1 << _WRITE_ACCU) | (1 << _READ_IR) | (1 << CLR_PC) | (1 << CLR_AKKU) );
	
	if (CU_ON_OFF_debounce_state.debounced_state == 0) {
		// Steuerwerk
		PORTD &= ~((1 << _EN_DEC) | (1 << _EN_CU) | (1 << _AUTO));
	} else {
		// Hand
		PORTD |= (1 << _EN_DEC) | (1 << _EN_CU) | (1 << _AUTO);
		
	}
	
	if (CLK_auto_ON_OFF_debounce_state.debounced_state == 0) {
		// automatischer Timer aus
		stoppe_automatischen_takt();
		if (CLK_manual_debounce_state.debounced_state == 1)
		{
			PORTB &= ~((1 << CLK_PIN) | (1 << CLK_LED_PIN));
		}
		else
		{
			PORTB |= (1 << CLK_PIN) | (1 << CLK_LED_PIN);
		}
	} else {
		starte_automatischen_takt();
	}
	
	//if (debounce_changeDetected(&RESET_debounce_state))
	//{
		//// der Reset-Button wurde gerade losgelassen
		//
		//// Signale aus dem Reset-Zustand herausnehmen
		//PIND &= ~((1 << _CLR_MPC) | (1 << _WRITE_ACCU) | (1 << _READ_IR) | (1 << CLR_PC) | (1 << CLR_AKKU));
//
		//if (CU_ON_OFF_debounce_state.debounced_state == 1) {
			//
		//}
		//
		//if (CLK_auto_ON_OFF_debounce_state.debounced_state == 1) {
			//// der automatische Takt ist an
			//starte_automatischen_takt();
		//}
		//
		//return;
	//}

	//if (debounce_changeDetected(&CLK_auto_ON_OFF_debounce_state))
	//{
		//if (CLK_auto_ON_OFF_debounce_state.debounced_state)
		//{
			//// der automatische Takt wurde gerade eingeschaltet
			//starte_automatischen_takt();
		//}
		//else
		//{
			//// der automatische Takt wurde gerade ausgeschaltet
			//stoppe_automatischen_takt();
		//}
	//}
	//
	//if (CLK_auto_ON_OFF_debounce_state.debounced_state == 1)
	//{
		//// der automatische Takt ist an
		//} else {
		//// der automatische Takt ist aus
		////
		//if (CLK_manual_debounce_state.debounced_state == 1)
		//{
			//PORTB = 0xff;
		//}
		//else
		//{
			//PORTB = 0;
		//}
	//}
}

int main(void)
{
	// Pins konfigurieren
	// DDR: 0: Eingang
	//      1: Ausgang

	// Pins für den Bonsai-Systamtakt als Ausgänge
	DDRB |= (1 << CLK_PIN) | (1 << CLK_LED_PIN);
	
	// Pins für die Schalter und Taster als Eingänge
	DDRC &= ~((1 < CLK_Speed) | (1 < CLK_auto_ON_OFF) | (1 < CLK_manual) | (1 < CU_ON_OFF) | (1 < RESET));
	
	// PORTC: Pullups aktivieren
	PORTC = 0xff;
	
	// Pins für _Auto, _EN_CU und _EN_DEC als Ausgänge
	DDRD |= (1 << _AUTO) | (1 << _EN_CU) | (1 << _EN_DEC);

	// Structs für Entprellung initialiseren
	CLK_Speed_debounce_state.debounced_state = GET_PIN(PINC, CLK_Speed);
	CLK_Speed_debounce_state.counter = 0;
	CLK_Speed_debounce_state.changeDetected = 0;
		
	CLK_auto_ON_OFF_debounce_state.debounced_state = GET_PIN(PINC, CLK_auto_ON_OFF);
	CLK_auto_ON_OFF_debounce_state.counter = 0;
	CLK_auto_ON_OFF_debounce_state.changeDetected = 0;
	
	CLK_manual_debounce_state.debounced_state = GET_PIN(PINC, CLK_manual);
	CLK_manual_debounce_state.counter = 0;
	CLK_manual_debounce_state.changeDetected = 0;
	
	CU_ON_OFF_debounce_state.debounced_state = GET_PIN(PINC, CU_ON_OFF);
	CU_ON_OFF_debounce_state.counter = 0;
	CU_ON_OFF_debounce_state.changeDetected = 0;
	
	RESET_debounce_state.debounced_state = GET_PIN(PINC, RESET)
	RESET_debounce_state.counter = 0;
	RESET_debounce_state.changeDetected = 0;

	// Timer für den automatischen Takt des Bonsai konfigurieren
	// CTC, Top OCR1A, normal Port Operation
	// WGM1 = 0100
	// Clock Select: clk/1024 (from prescaler)
	// Interrupt OutputCompare A aktivieren
	TCCR1B |= (1 << WGM12);	
	TIMSK1 |= (1 << OCIE1A);

	OCR1A = 1000;
	
	//if (CLK_auto_ON_OFF_debounce_state.debounced_state) {
		//// automatischen Takt einschalten
		//starte_automatischen_takt();
	//}
	
	
	// Timer für den Systemtakt des ATmega konfigurieren
	// CTC, TOP OCRA , normal Port Operation
	// WGM = 010
	// Clock Select: clk/256 (from prescaler)
	//TCCR0A |= (1 << WGM01);
	//TCCR0B |= (1 << CS02);
	//TIMSK0 |= (1 << OCIE0A);	
	//OCR0A = 4;
	
	// ------------------------
	// Ausgänge initialisieren
	// ------------------------
	
	if (CLK_auto_ON_OFF_debounce_state.debounced_state == 1)
	{
		// der automatische Takt ist an
		starte_automatischen_takt();
	}
	else
	{
		// der automatische Takt ist aus
		if (CLK_manual_debounce_state.debounced_state == 1) {
			clk_off();
		} else {
			clk_on();
		}
	}
	
	if (CU_ON_OFF_debounce_state.debounced_state) {
		enable_cu();
		enable_auto();
	} else {
		disable_cu();
		disable_auto();
	}
	
	// ------------------------
	
	
	sei();
	
    while (1)
    {	
		tick_loop();	
		_delay_ms(1);
    }
}



uint8_t debounce_changeDetected(volatile Debounce_state *state) 
{
	if (state->changeDetected)
	{
		state->changeDetected = 0;
		return true;
	}
	else
	{
		return false;
	}
}

ISR (TIMER1_COMPA_vect)
{
	if (PINB & (1 << CLK_PIN)) {
		// Der Takt ist 1
		// Takt auf 0 setzen
		//PORTB &= ~((1 << CLK_PIN) | (1 << CLK_LED_PIN));
		clk_off();		
	} else {
		// Der Takt ist 0
		// Takt auf 1 setzen
		clk_on();
		//PORTB |= (1 << CLK_PIN) | (1 << CLK_LED_PIN);
	}	
			
	if (CLK_Speed_debounce_state.debounced_state) {
		// schnell		
		OCR1A = 5;
	} else {
		// langsam
		OCR1A = 1000;
	}
}

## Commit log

2020-10-15 Akku: Bauteilwerte ergänzt
    [Akku.kicad_pcb, Akku.sch]
2020-10-15 Akku: Schaltungen zum entprellen der Taster gleichartig angeordnet
    [Akku.kicad_pcb, Akku.sch]
2020-10-22 LEDs richtig rum gedreht
    [speichermodul.kicad_pcb, speichermodul.sch]
2020-10-24 redesign Steuerwerk angefangen
    [Steuerwerk.kicad_pcb, Steuerwerk.sch]
2020-10-24 vor Umbau 74541 im Schaltplan
    [Steuerwerk.kicad_pcb, Steuerwerk.sch]
2020-10-24 Steuerwerk: beide 74541 umgebaut
    [Steuerwerk.kicad_pcb, Steuerwerk.sch]
2020-10-24 Steuerwerk vor Entfernen der Busse
    [Steuerwerk.kicad_pcb, Steuerwerk.sch]
2020-10-25 Steuerwerk weitergemacht
    [Steuerwerk.kicad_pcb, Steuerwerk.sch]
2020-10-25 Steuerwerk fertig außer Diodenmatrix
    [Steuerwerk.kicad_pcb, Steuerwerk.sch]
2020-10-25 Steuerwerk fast fertig TODO: Beschriftung überarbeiten
    [Steuerwerk.kicad_pcb, Steuerwerk.sch]
2020-10-26 Steuerwerk: - Sperrbereiche für die Köpfe der Befestigungsschrauben hinzugefügt - Beschriftung (Silkscreen) auf der Platinenoberseite bearbeitet
    [Steuerwerk.kicad_pcb, Steuerwerk.sch]
2020-10-28 viele Kleinigkeiten
    [Steuerwerk.kicad_pcb, Steuerwerk.sch]
2020-10-30 Steuerwerk: Verbinder für die beiden unbenutzten Steuersignale eingebaut
    [Steuerwerk.kicad_pcb, Steuerwerk.sch]
2020-10-30 Steuerwerk: Platzhalter für LEDs eingefügt
    [Steuerwerk.kicad_pcb, Steuerwerk.sch]
2020-10-30 Line Width im Silkscreen an die Vorgaben con jlcpcb angepasst
    [Steuerwerk.kicad_pcb]
2020-10-30 Steuerwerk: weitere Platzhalterdioden eingebaut
    [Steuerwerk.kicad_pcb, Steuerwerk.sch]
2020-10-31 Steuerwerk: Linien im Silkscreen in den Footprints der LEDs in der Diodenmatrix entfernt
    [Steuerwerk.kicad_pcb]
2020-10-31 Steuerwerk: alle Diodenplatzhalter eingebaut
    [Steuerwerk.kicad_pcb, Steuerwerk.sch]
2020-10-31 Steuerwerk: EdgeCuts verschoben
    [Steuerwerk.kicad_pcb]
2020-10-31 Steuerwerk rev 2.0
    [Steuerwerk.kicad_pcb, Steuerwerk.sch]
2020-10-31 Befehle: vor Umbau der Diodenmatrix im Schalplan
    [Befehle.kicad_pcb, Befehle.sch]
2020-10-31 Befehle: Schaltplan bearbeitet
    [Befehle.kicad_pcb, Befehle.sch]
2020-11-01 Befehle: Schaltplan geändert
    [Befehle.kicad_pcb, Befehle.sch]
2020-11-05 Steuerwerk und Befehle bearbeitet
    [Befehle.kicad_pcb, Befehle.sch, Steuerwerk.kicad_pcb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]
2020-11-06 Footprint EuroBoard gedreht und auf das Gitter gelegt (Ursprung links oben)
    [Befehle.kicad_pcb, Steuerwerk.kicad_pcb]
2020-11-06 Befehle: An der Platine weitergearbeitet
    [Befehle.kicad_pcb, Befehle.sch, Steuerwerk.kicad_pcb]
2020-11-07 Befehle: Platine fertig (TODO: Kontrolle)
    [Befehle.kicad_pcb, Befehle.sch]
2020-11-07 Backup vor Umbennung von Netzen
    [Akku.kicad_pcb, Akku.sch]
2020-11-07 Akku/PC: Schaltplan mit Bussen gezeichnet; Netze der Busse sinnvoll benannt
    [Akku.kicad_pcb, Akku.sch]
2020-11-07 Akku/PC: Schaltplan aufgeräumt
    [Akku.kicad_pcb, Akku.sch]
2020-11-08 Steuerwerk: keine verstecken Pins mehr; alle Pins explizit im Schaltplan angeschossen
    [Steuerwerk.sch]
2020-11-08 Befehle: alle versteckten Pins durch sichtbare Pins ersetzt; VCC und GND an jedem IC explizit im Schaltplan angeschlossen.
    [Befehle.sch]
2020-11-15 Steuerwerk 2.0 gerber exportiert
    [Akku.kicad_pcb, Akku.sch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]
2020-11-15 Befehle und Steuerwerk: - Kleinkram - gerber rev 2.0 für Bestellung exportiert
    [Befehle-B_Cu.gbr, Befehle-B_Mask.gbr, Befehle-B_SilkS.gbr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]
2020-11-29 Akku weitergebaut
    [Akku.kicad_pcb, Akku.sch]
2020-12-04 Bauteilwerte in Benutzerebene angezeigt
    [Befehle.kicad_pcb]
2020-12-18 Akku/PC Layout angefangen
    [Akku.kicad_pcb, Akku.sch, Steuerwerk.kicad_pcb]
2020-12-18 Akku Board weiter
    [Akku.kicad_pcb]
2020-12-18 Akku Layout weitergemacht
    [Akku.kicad_pcb]
2020-12-18 Speichermodul weitergebaut
    [speichermodul.kicad_pcb, speichermodul.sch]
2020-12-19 Speicher weitergebaut
    [speichermodul.kicad_pcb, speichermodul.sch]
2020-12-20 Speicher Layout EinTaktReset VCO
    [EinTaktReset.kicad_pcb, EinTaktReset.sch, speichermodul.kicad_pcb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]
2020-12-20 Speicher vor Tausch der Taster
    [speichermodul.kicad_pcb, speichermodul.sch]
2020-12-20 Speicher fertig*
    [speichermodul.kicad_pcb]
2020-12-22 Akku, Speicher, EinTaktReset: Via-Durchmesser vergrößert
    [Akku.kicad_pcb, EinTaktReset.kicad_pcb, speichermodul.kicad_pcb]
2020-12-23 viele kleine Änderungen
    [Akku-B_Cu.gbr, Akku-B_Mask.gbr, Akku-B_SilkS.gbr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]
2020-12-23 Netze umbenannt
    [EinTaktReset.kicad_pcb, EinTaktReset.sch]
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2021-08-01 Revision auf allen Schaltplänen eingetragen
    [Akku.sch, Befehle.sch, EinTaktReset.sch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]
2021-10-12 Readme angepasst Kabelhalter eingefügt
    [Kabelhalter.scad]
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2024-03-11 - alles auf KiCad 7 umgestellt - EinTaktReset neu (mit Mikrocontroller)
    [Akku.kicad_pcb, Akku.kicad_sch, Akku.sch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]
2024-03-11 - Werte von Bauteilen in den Schaltplänen ergänzt - weitere Hinweise zum Nachbau
    [Akku.kicad_sch, Befehle.kicad_sch, EinTaktReset.kicad_sch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]
2024-08-11 schmale Platine für die Spannungsversorgung
    [power-B_Cu.gbl, power-B_Mask.gbs, power-B_Paste.gbp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]
2024-08-11 Alle Vorwiderstände vor LEDs in 680 Ohm geändert (Issue 5)
    [Akku.kicad_pcb, Akku.kicad_sch, Befehle.kicad_pcb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]
